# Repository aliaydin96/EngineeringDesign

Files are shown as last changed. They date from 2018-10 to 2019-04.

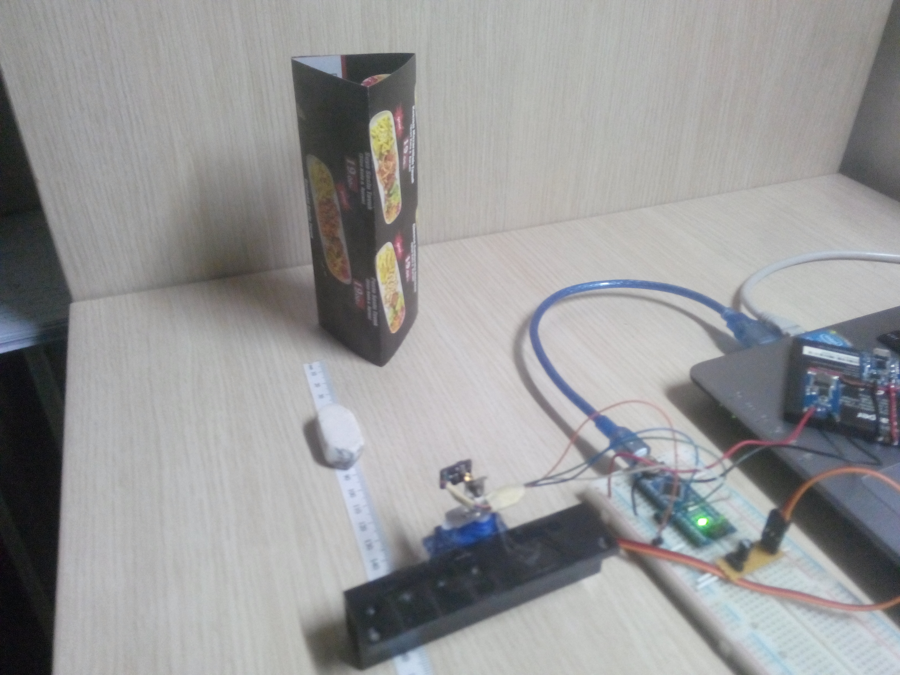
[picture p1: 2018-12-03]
Algorithm/measurements/IMG_20181125_203048.jpg

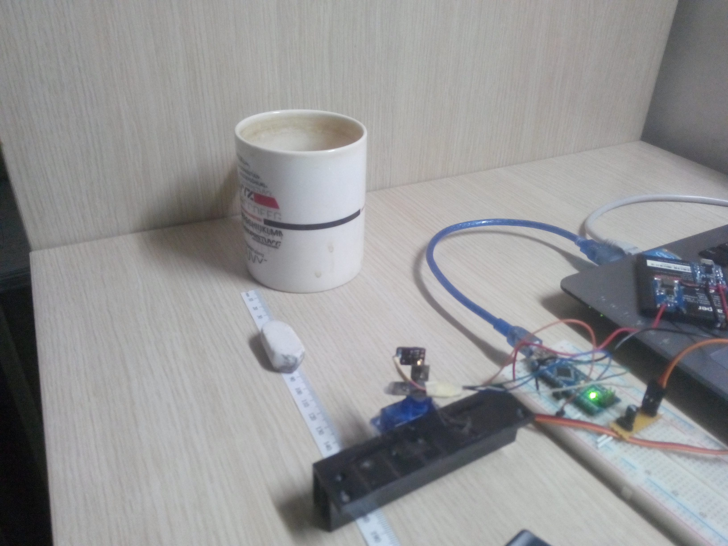
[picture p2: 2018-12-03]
Algorithm/measurements/IMG_20181125_203109.jpg

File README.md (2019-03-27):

# Coni nolur yeni branch açma :*
## Deadlines
* Weekly Reports every monday nights 00:00
* IMPLEMENTATION DEADLINE April 22-26
* FINAL REPORT IS DUE May 10th, Friday (17:00)
* FINAL DEMO (May 13‐ 17 May)
* EE494 - PROJECT FAIR June 14th

## Not To Do (Important!) 
* Öncelikle dosyasınızı başka bir konumda düzenleyin. Pull yapın sonra düzenlediğiniz dosyayı EngineeringDesign klasörüne atıp push yapın.
* Not push before pull! (alan el veren elden üstündür.)
* Never ever try to open another branch
* No fetch, merge, weird forks and anything fancy
* If your push give error do **NOT** force-push. There is no **force-pull** option at the another side.

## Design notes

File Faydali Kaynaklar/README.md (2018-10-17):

# Useful links
## OpenSimpleLidar
[Github Repo](https://github.com/iliasam/OpenSimpleLidar)
## xLIDAR
[Github Repo](https://github.com/JRodrigoTech/xLIDAR)
## LiDAR-Lite v3 ($129.99)
[SparkFun Link](https://www.sparkfun.com/products/14032)
## TFMini Micro LiDAR Module ($39.95)
[SparkFun Link](https://www.sparkfun.com/products/14588)

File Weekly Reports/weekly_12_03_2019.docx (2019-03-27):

RALAZABA Electronics

Weekly Report

Team Members: Ali AYDIN, Anıl AYDIN, Enes AYAZ, Selman DİNÇ, Nail TOSUN

Advisor: Lale ALATAN

Done

We acquired measurements from multiple sensors simultaneously such that the environment sensing unit can achieve 360-degree vision of the environment. The results are explained in Sensor Employment section.

We established the mechanical design and are currently working on 3D Printed parts of Environment Sensing Unit and Self Localization Unit

To Do

We will finish mechanical design and obtain a stable system such that all the components of the robot are placed in the chassis and fixed.

Sensor Employment

In this study, we tested the ability of visualization of the environment using four-fused sensors. The tests took place in the figure 1. As shown in the figure, a cylinder with 5 cm diameter placed at (0 cm,0 cm), a cylinder with 10 cm diameter placed at (54 cm,0 cm) and a triangular prism with 7 cm edge-length placed at (40 cm, -47 cm).

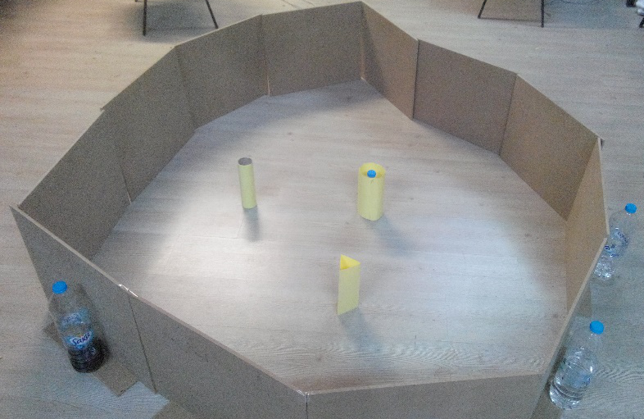
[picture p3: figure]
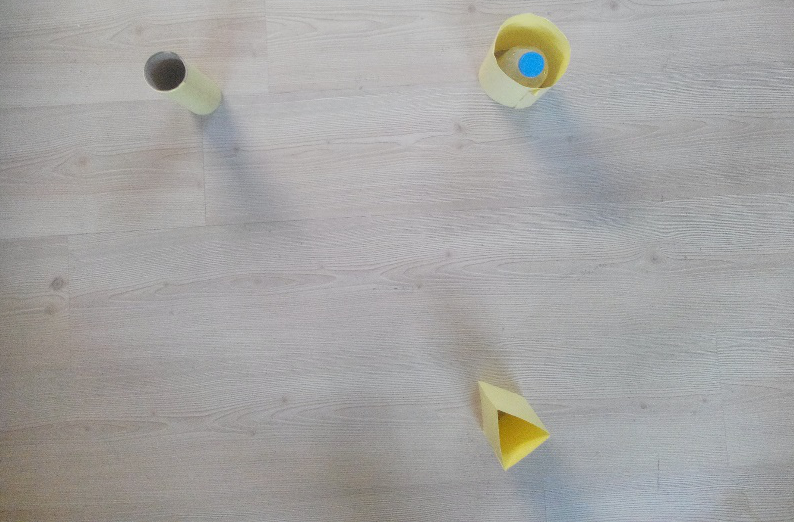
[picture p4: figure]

Figure 1 The test setup

The first measurement was taken from (24 cm,0 cm) point and it is shown in figure 2.

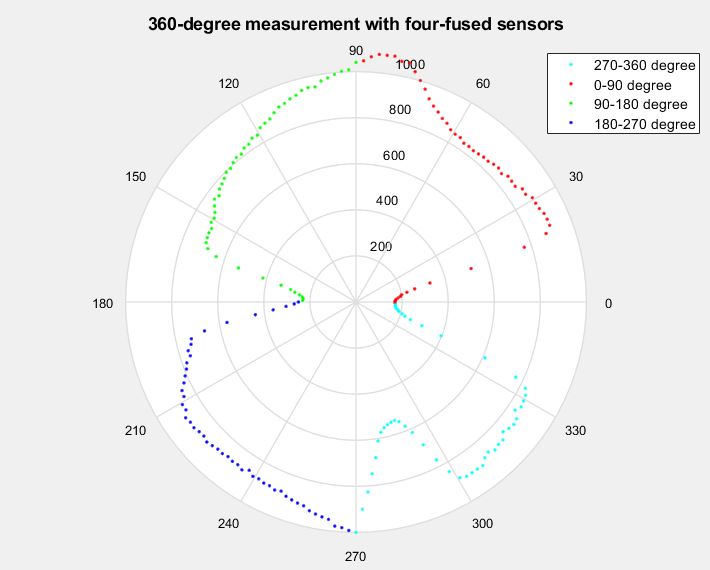
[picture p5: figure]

Figure 2 The first measurement under fluorescent illumination (similar to the case in Cultural Convention Center.)

From the figure 2, the peak for the cylinder with 10 cm diameter is measured at (186mm, 0 mm) and the peak for cylinder with 5 cm diameter is measured at (220mm, 0 mm), which results in app. %3 error.

To test the effect of the sunlight exposure, we took the same measurement under direct sunlight illumination. The result is shown in figure 3.

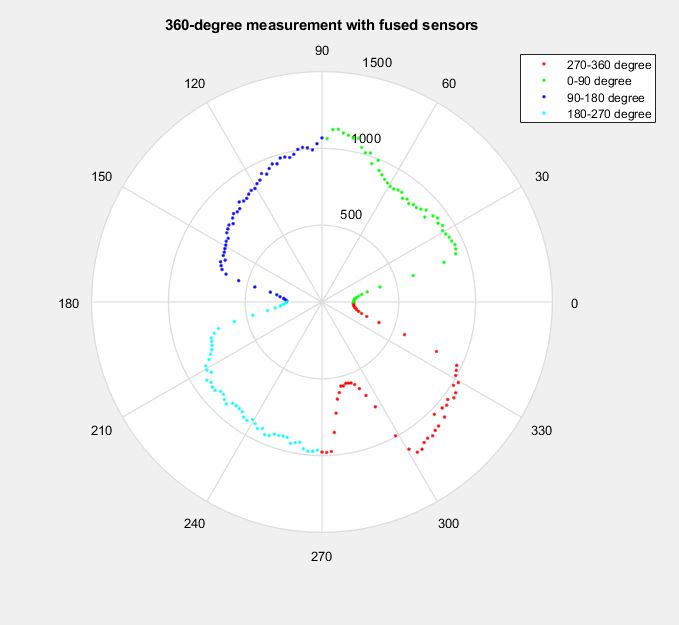
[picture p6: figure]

Figure 3 The first measurement under direct sunlight illumination

At this point, the peak of the left cylinder is at (215mm, 0mm) and the peak of the right cylinder is at (198mm, 0mm). This is expected due to sensor characteristics.

Then, the second measurement was taken at (24 cm, -30 cm) and used to build the resultant map as shown in figure 4. In this figure, the higher portion of the noise does not affect the result significantly. However, for the triangular prism the measurements are shifted. This may occur because of accidental move of the triangular object.

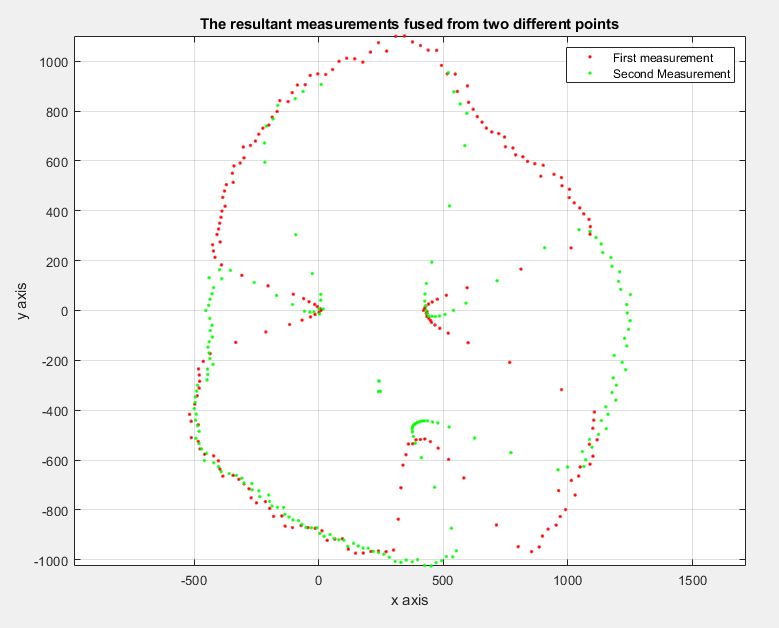
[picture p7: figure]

Figure 4 The resultant map

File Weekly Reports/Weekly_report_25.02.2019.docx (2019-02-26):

RALAZABA Electronics

Weekly Report

Team Members: Ali AYDIN, Anıl AYDIN, Enes AYAZ, Nail TOSUN, Selman DİNÇ

Advisor: Lale ALATAN

Done

Two mouses self-localization method is tested.

We wrote test procedures for both mouse option and encoder readings

To Do

Encoder readings will be tested and compared with the the mouse option.

Kalman Filter will be constructed.

Mechanical design will be built.

Kalman Filter Road-Map

At the conceptual design report, we proposed 5 different ways to sense the robot’s localization. We chose two methods together in order to prevent cumulative errors at the location and heading angle. Therefore, we decided to use a Kalman filter. In order to use a Kalman filter, we should have two measuring methods one is more accurate less frequent other one vice versa.

Our methods to sense location of the robot are two mouses method and encoder reading. To measure how much cumulative error can cause problems at the robot’s operation we wrote a test procedure for two mouse method. Our first thought is the mouse method has better accuracy but sensor data less frequent. The encoder readings are real-time but noisier. However, calculation errors of both two methods are crucial for filter design.

This week, we measure the error of two mouses method. Following week, we will test the encoders.

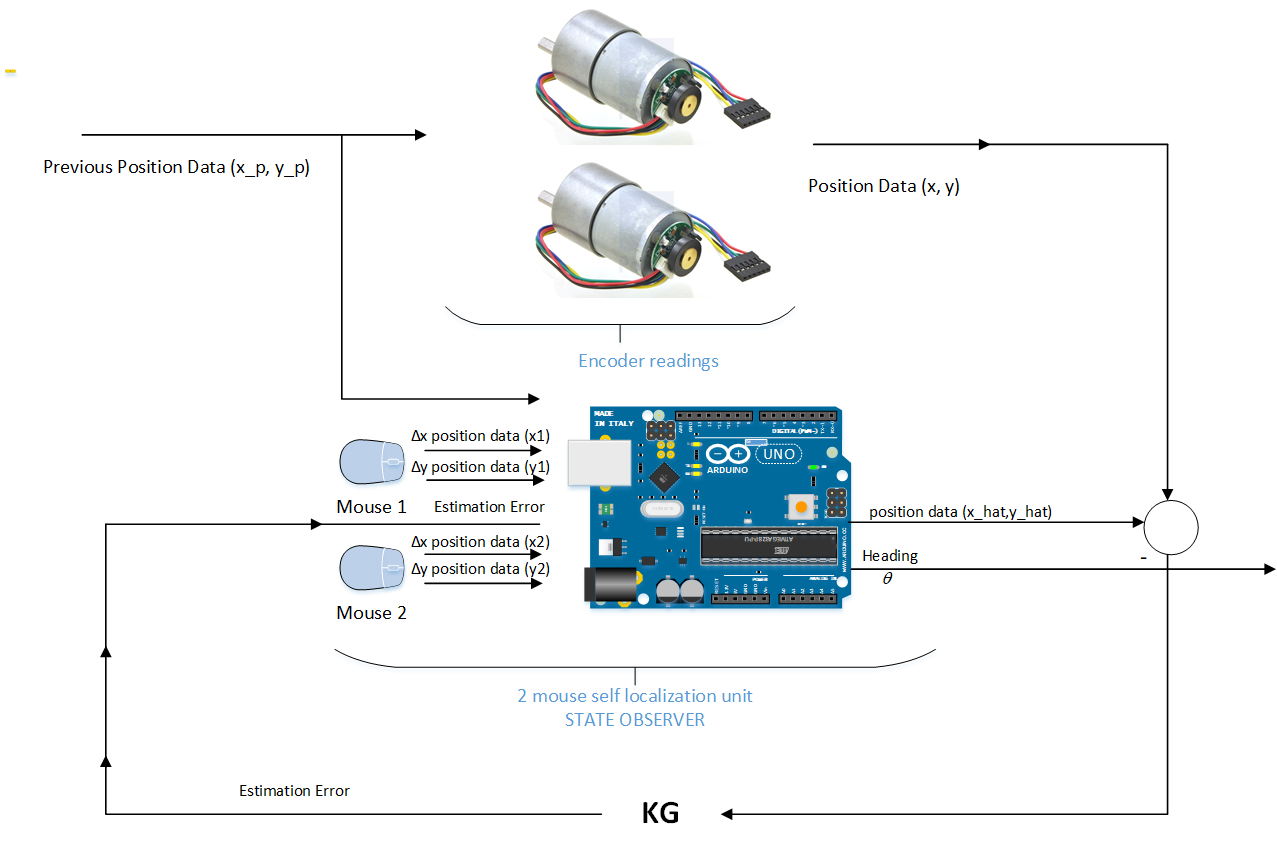
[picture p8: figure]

Figure 1 Kalman Filter Block Diagram

Self-localization (State Observer) Test Procedure

Test Plan

We want to use the 2 mouse method to solve the self-localization problem. In this method 2 separate mouse’s combined to measure both relative distance and heading angle of the robot. To measure errors of this method we planned a test plan.

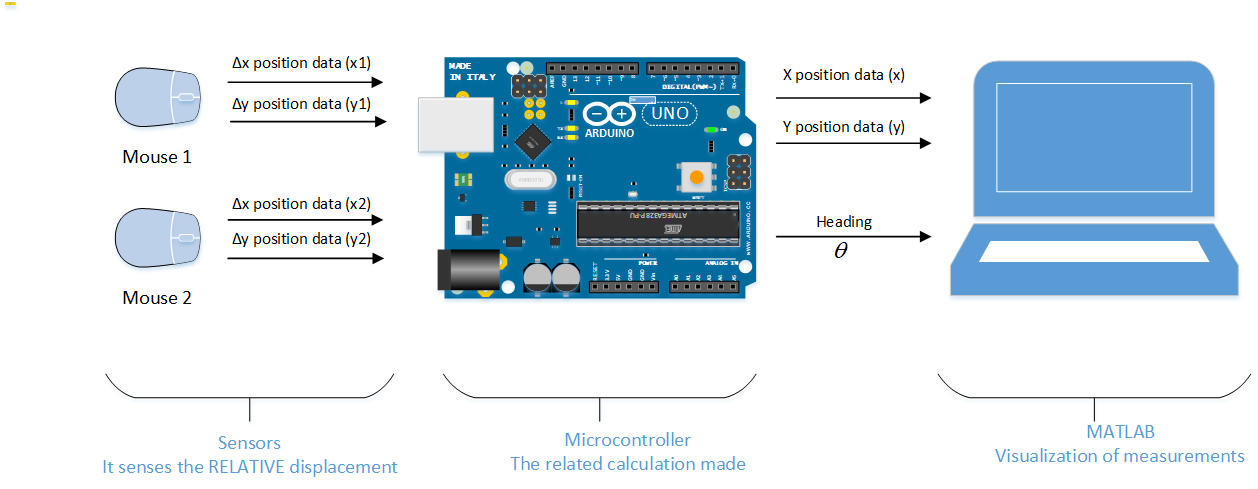
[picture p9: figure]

Figure 2 Block Diagram of the Test Plan

Test Setup

We read the sensor data with Arduino Nano. The related calculations made at MATLAB and Arduino environments. We measure the ground truth using millimetric papers.

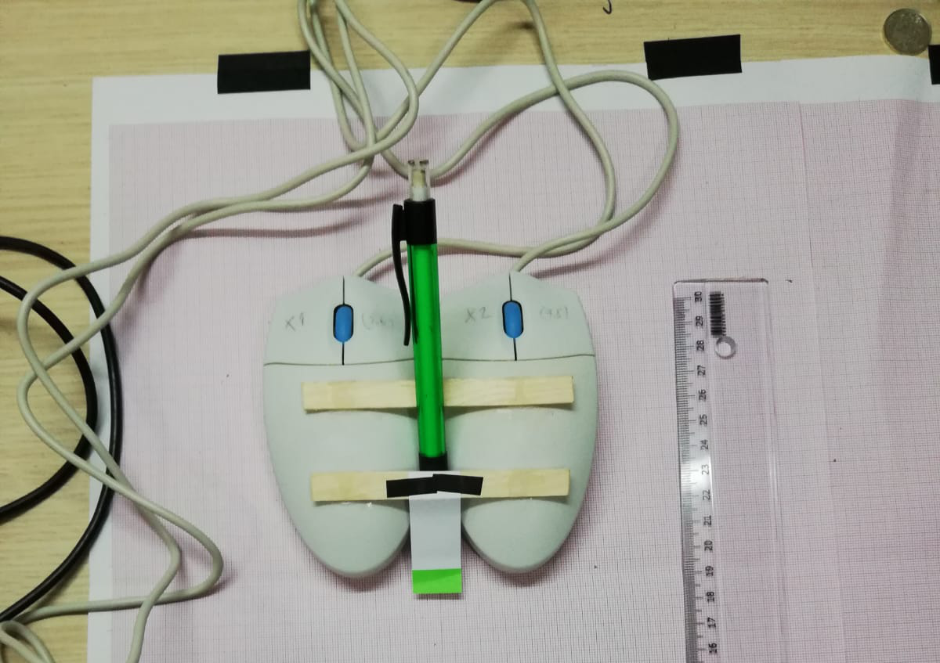
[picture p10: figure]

Figure 3 Test Setup

Test | Expectation
Straight Line 1 at a small distance | Is the unit measure the distance with MEA less than %1?
Straight Line 2 at large distance | Is unit measure the distance with MEA less than %1 Is the effect of cumulating the error seen?
2 Direction movement at an acute angle ( θ<90 ° ) | Is the unit measure the heading angle with MEA less than 1 ° ?
Arc (Quarter circle) | Is the unit measure the final destination with MEA less than %1? Is the unit measure the heading angle with MEA less than 1 ° ?

Table 1: Test Procedure

Test Results

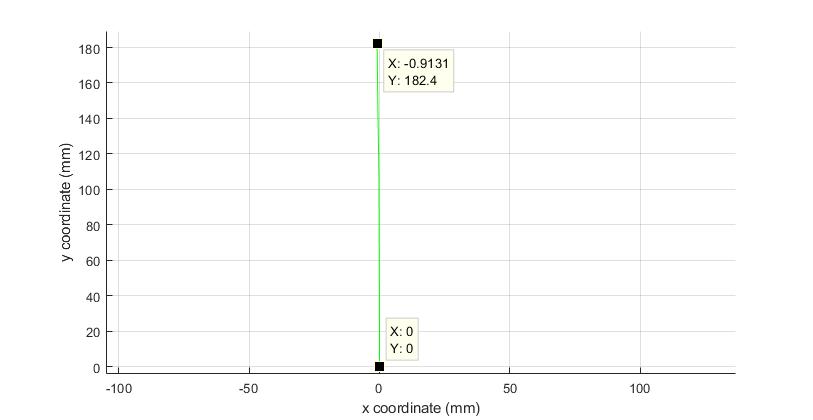
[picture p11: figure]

Figure 4: Test 1 short distance measurement

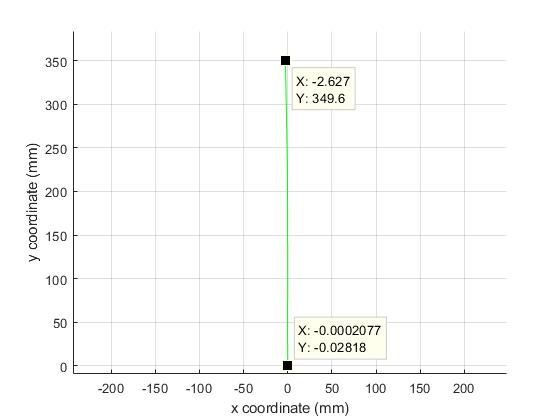
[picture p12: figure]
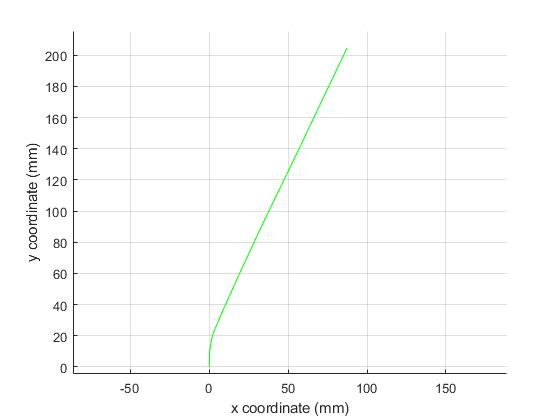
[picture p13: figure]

Figure 5: Test 2 Long distance measurement | Figure 6: Test 3 heading angle

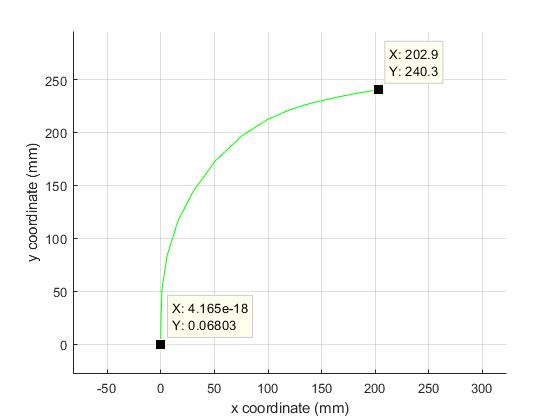
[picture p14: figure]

Figure 7 Test 4 Arc

Errors

Test No | Ground Truth | Measurement | Error PMAE
1 | x = 182 mm | x = 182.4 mm | 0.2 %
2 | x = 350 mm | x = 349.6 mm | 0.11 %
3 | θ=65.5 ° | θ=65.12 ° | 0.58 %
4 | x = 210 mm y = 210 mm | x = 202.9 mm y = 240.3 mm | 7.9%

Table 2 Errors

Conclusion of the test

From these test result we conclude that;

- Two mouse method high accuracy when the motion of basic. (Straight line, L shapes etc.)
- When the roadmap getting complex, the error due to measure is grow cumulatively. Therefore, roadmap algorithm should be robust or cumulative errors should be deleted via filters, i.e. Kalman filter.
- Very possible reason for failure at test for is our system is not sensitive lateral movements like in figure x
- In the case of differential drive there will be no direct horizontal movements or serious horizontal disturbances. Therefore, test 4 error is not critical for our sensing subunit. However, related software update will be constructed next week.

Figure 8: Illustration of horizontal disturbances

Next Week Test Procedures

Test | Expectation
Straight Line 1 at a small distance | Is the unit measure the distance with MAE<% 1?
Straight Line 1 at a long distance | Is the unit measure the distance with MAE<% 1? Is the effect of cumulating the error seen?
2 Direction movement at an acute angle | Is the unit measure the heading angle with MAE<% 1?
2 Direction movement at a wide angle | Is the unit measure the heading angle with MAE<% 1? Is the effect of cumulating the error seen?
Arc (Quarter circle) | Is the unit measure the final destination with MAE<% 1? Is the effect of cumulating the error seen?
Random Path | Is the unit measure the 5 random destination point with average MAE<% 1? Is the unit measure the heading angle with MAE<% 1? Is the effect of cumulating the error seen?
Overall System (Conclusion) | Is the method satisfy our performance requirements?

Figure 9: Test procedures for both mouse and encoder methods

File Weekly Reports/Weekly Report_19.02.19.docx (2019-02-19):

RALAZABA Electronics

Weekly Report

Team Members: Ali AYDIN, Anıl AYDIN, Enes AYAZ, Nail TOSUN, Selman DİNÇ

Advisor: Lale ALATAN

Done

- We tested the accuracy of the distance sensors that we purchased and check the consistency of the sensor under various illumination.
- We tried to drive multiple sensors more than two. We achieved to drive two sensors instantaneously.
- We tested the two-mouse structure to find the heading and location. We failed in algorithm. We conclude our work with the result that we need to re-design our algorithm.

To Do

- We will re-design our self-localization algorithm and will test it.
- We will purchase mechanical chase casing and built it.
- We will focus our research on Critical Design Review Report.

Sensor tests

The experiment is made to test the effect of illumination. In the test environment, the illumination is made by 50-lux fluorescent lamp placed right above the sensor and the object. As a result, the measurements are consistent with the given datasheet and the sensors work flawlessly.

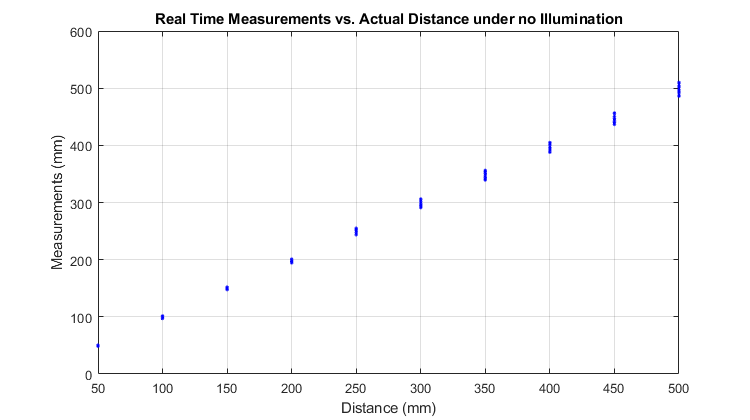
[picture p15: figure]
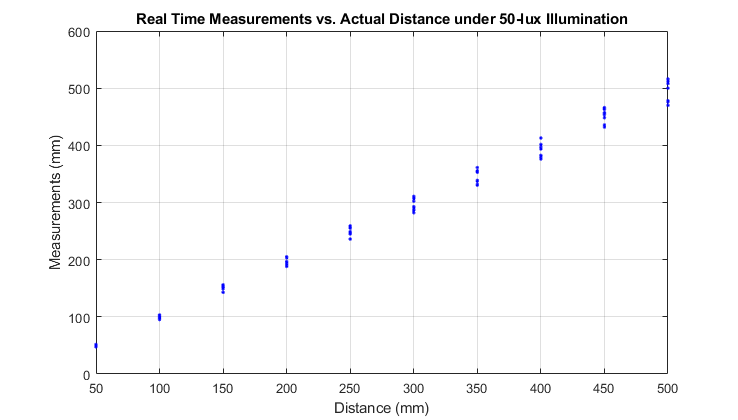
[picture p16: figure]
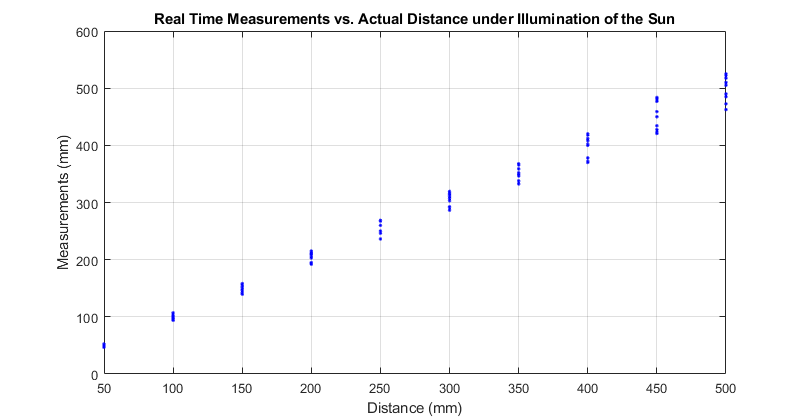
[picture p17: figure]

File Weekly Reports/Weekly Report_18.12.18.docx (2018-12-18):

RALAZABA ELECTRONICS

Weekly Report

Team Members: Ali AYDIN, Anıl AYDIN, Enes AYAZ, Nail TOSUN, Selman DİNÇ

Advisor: Lale ALATAN

Done

- We tried to control the mouse on MATLAB and we drew the path of mouse without using any rotation angle. We just drew on XY plane. The result can be seen in Figure 15.
- We tried to obtain rotation angle by using gyroscope, we realized it only gives information about the direction gravity vector and its rotational output is not reliable. Due to that, we decided to use compass or two mousses to sense rotation of robot.
- We created a simulation environment for shape and center detection. The maps and shapes are in the section of “Shape and center detection simulation”
- After that, we tried to use measured data for shape detection, but our measured data needs to be cleaned in some aspect. For that, we made a modification in our algorithm. The explanation of the modification and the results with measured data is in the section of “shape finder algorithm for measured data”.

To Do

- We will start to write conceptual design report on Wednesday.
- We will try to obtain rotation angle by using two mouse or a mouse and compass.

Shape and center detection simulation

To test our first algorithm for shape and their center detection, we created simple maps with no error using paint. The maps that we tested are shown in from Figure 1 to Figure 4.

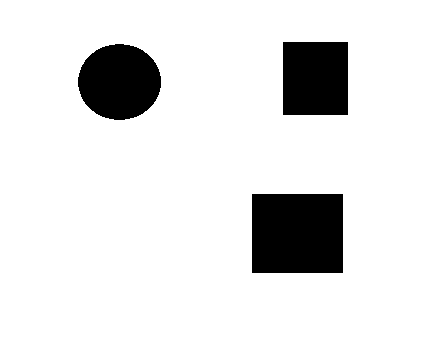
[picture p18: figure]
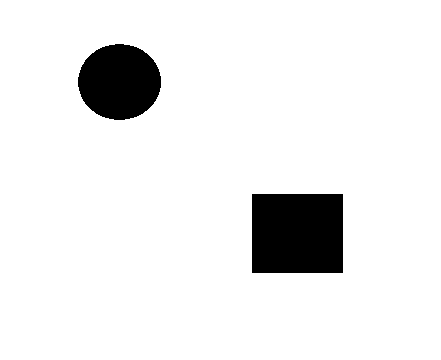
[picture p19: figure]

Figure 1: First Test Map Figure 2: Second Test Map

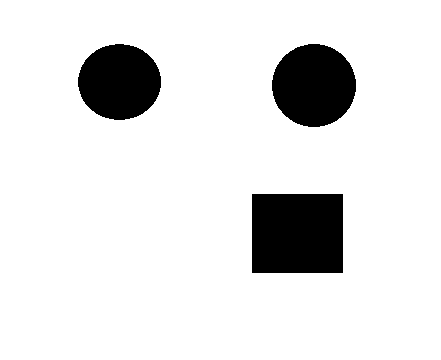
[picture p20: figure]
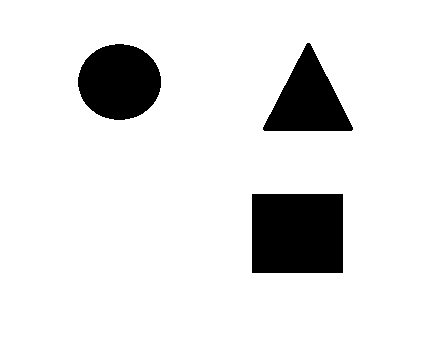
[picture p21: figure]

Figure 3: 3rd Test Map Figure 4:4th Test Map

We created a simulation environment such that, we loaded these maps to a MATLAB script and we selected 3 points for sensing these shapes. From these 3 points, we created lines with different slopes and the intersection points represented the lidar scans. These lines will represent how the map will be seen by the lidar sensor. Our simulation environment is seen like in Figure 5. In the figure, the lines (lidar measurements) is intercepted with the boundaries of the objects. The interceptions are shown in the figure as red dots. The intersection points for 4 different map configurations are shown in from Figure 6 to Figure 9.

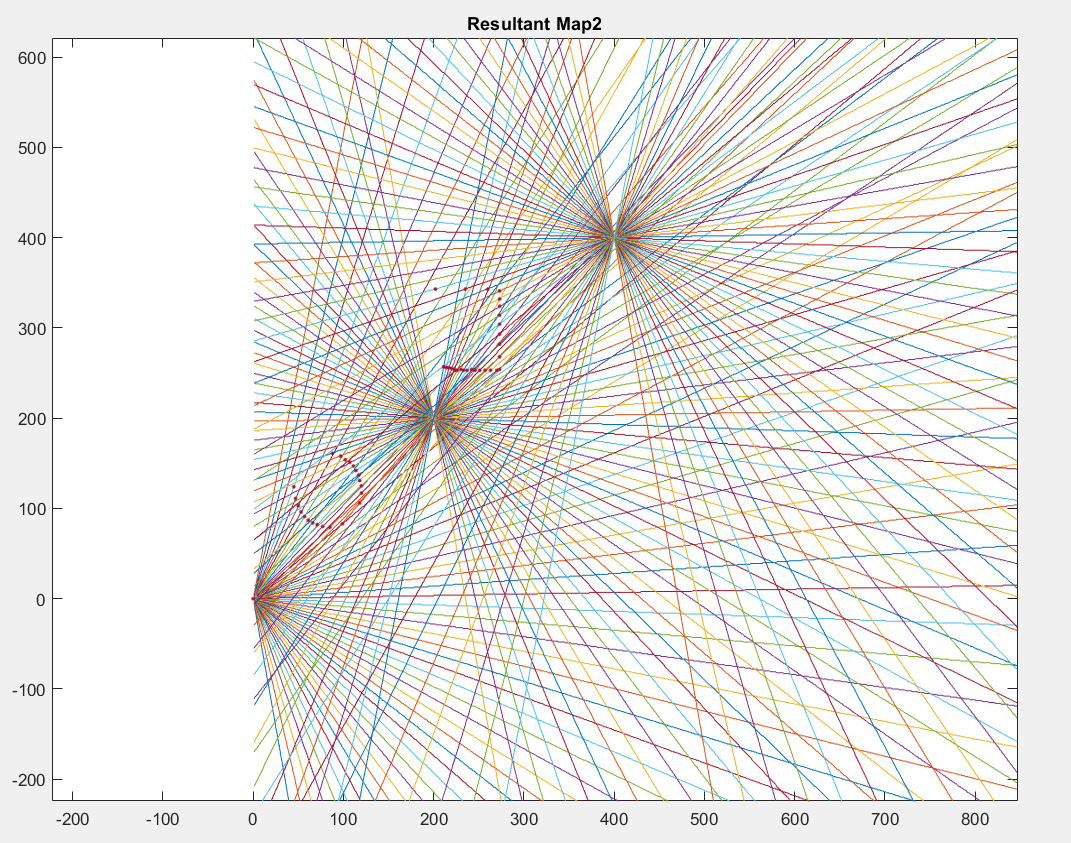
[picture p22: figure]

Figure 5: The simulation environment

After intersecting lines and our objects, some parts of objects are not shown which will be the case in real data. The missing parts of the objects can be seen in resultant maps. We must come up with this problem first. To do that, we combined x and y coordinates of resultant map data and converted these data to an image to be able to process and create objects.

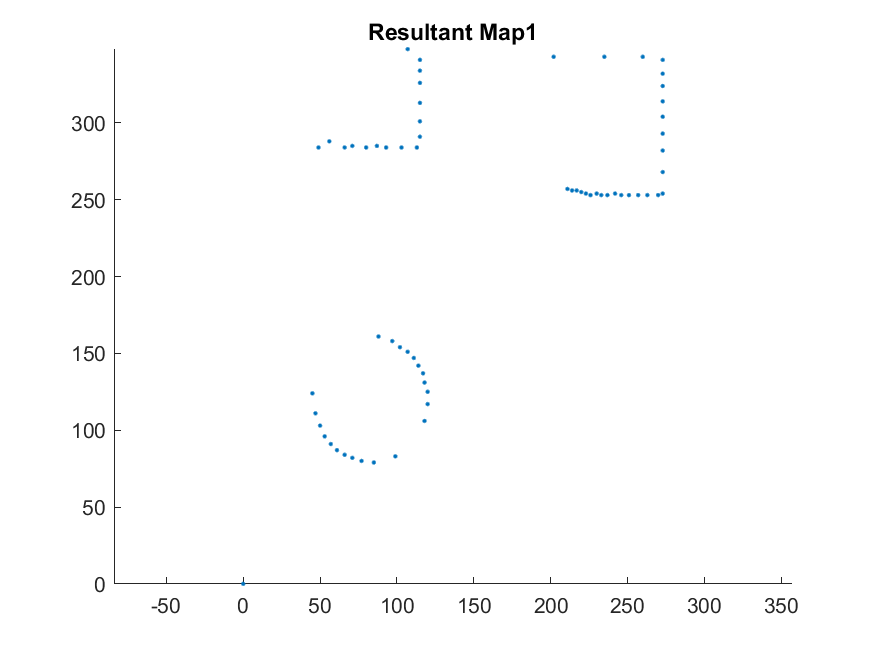
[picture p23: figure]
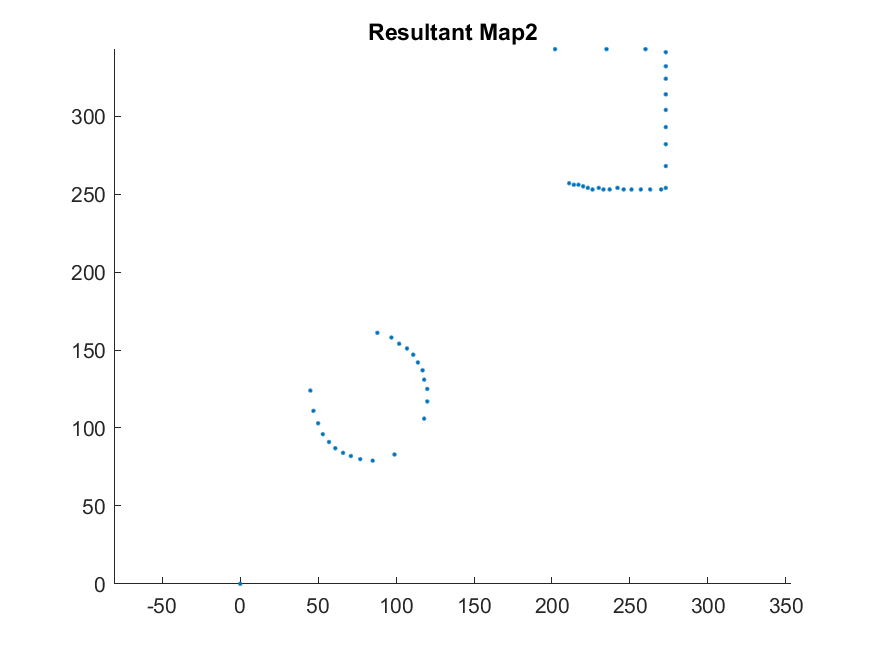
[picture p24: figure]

Figure 6: Lidar Scan Result for 1st Map Figure 7: Lidar scan result for 2nd Map

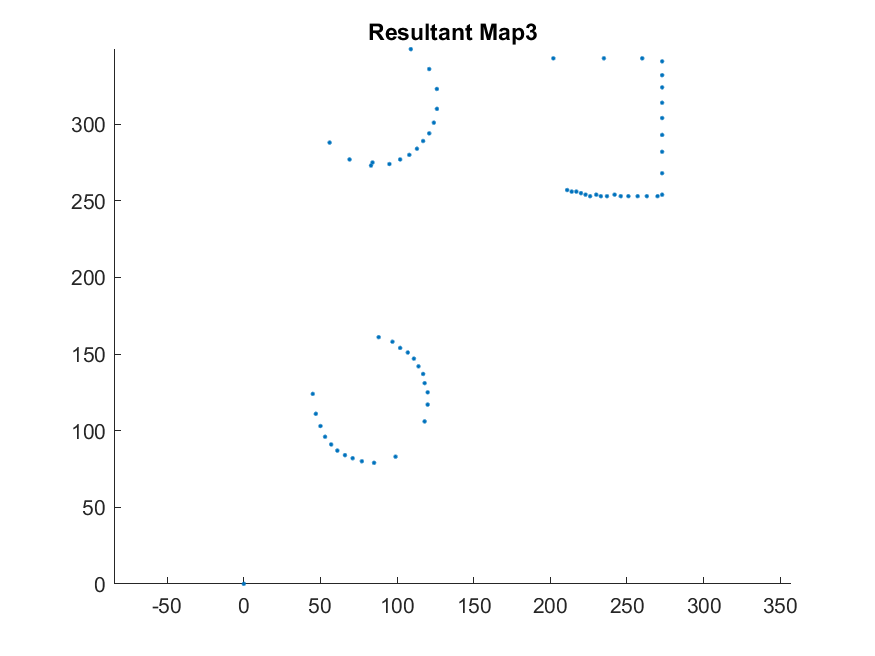
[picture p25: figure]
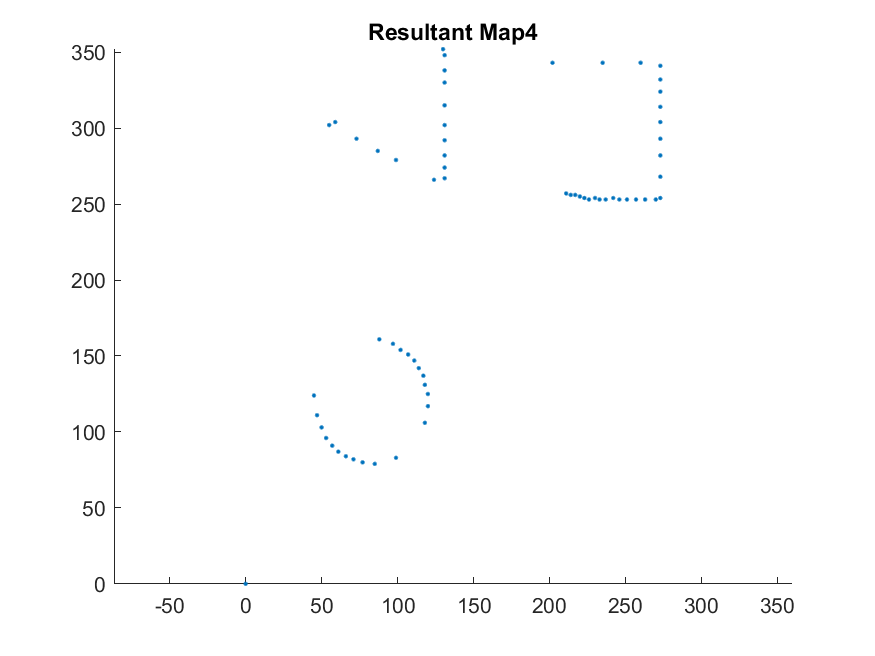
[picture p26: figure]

Figure 8: Lidar Scan result for 3rd Map Figure 9: Lidar Scan Result for 4th Map

Thus, after simulation, we converted resultant maps to images and made threshold operations. The thresholding operation is used to determine the boundaries and edges of the objects for Multiple Kernels. Further readings can be found under the topic “Multiple Kernels for Object Detection”. After thresholding, we found contours in the image and using some constraints such as the area of contours and the length of contour arrays, we created 3 different cases for rectangular, circular and triangular objects. The resultant maps from the missing data are shown in from Figure 10 to 13.


Figure 10:Resultant shapes and centers for 1st Map Figure 11: Resultant shapes and centers for 2nd Map


Figure 12:Resultant shapes and centers for 3rd Map Figure 13:Resultant shapes and centers for 4th Map

Yet, we have some problems about our algorithm which is detection of the triangular object is not working well. We will solve this problem by defining the triangle dimensions to the software as we know them.

Measurement

We set the measurement environment to test our mapping algorithm with real data. The setup, Figure 14-16, has 3 different viewpoints with respect to object. The test objects are scanned via the lidar sensor from three different points. These measurements are merged by using an algorithm that takes a position of sensor (in 2 Dimension) and angle between stationary coordinate system and sensor data. Normally, the lidar will measure the distance with related angle. This angle information is in the frame of the lidar. We need to project the measurements to the global frame of the map. To accomplish this task, the measurements are rotated using rotational transformation matrix and positioned according to the position vector of the lidar. The output of algorithm is illustrated in Figure 14 to 16.

Later, the obtained data will be fed to the object finder algorithm.


Figure 14 First Test Map and its output


Figure 15 Second Test Map and its output


Figure 16 Third Test Map and its output

Outputs of shape finder algorithm for real measured data

When we tested our shape finder algorithm with real erroneous data, we had some problem. Most important problem is that the spaces between measured points are large and this causes that our algorithm can find wrong contours. To eliminate this, we added new points to resultant array by adding neighbor points of real data clouds. After that, our thresholding operation worked and we were able to find true contours. The output for rectangular object is shown in Figure 17. We found the center of rectangle as 146,135. The real center was 146,140. This means that we had 3% error for y coordinate of center.


Figure 17: Output of rectangular object

The output for cylindrical object is shown in Figure 18. For cylindrical object we found the center as 154,135. Real center was 146,140. Thus, we had 6% error for x coordinate and 3% for y coordinate.


Figure 18: Output of cylindrical object

The output for triangular object is shown in Figure 19. Here, we found the center as 148,146. Real center was 184,130. We had 24% error for x coordinate and 12% error for y coordinate.


Figure 19: Output of triangular object

These results show us that, while measuring data, we need to have some improvements for better mapping since we need very clear input for shape finding in our case. Another result is that to detect and find the shape of triangular object is hard and, we must modify our shape finding algorithm for more accurate results.

For Mouse Application

We connected a trackball mouse to Arduino and to obtain a graph, and we took data on serial port by using MATLAB. Therefore, as seen Figure 20, we track mouse on the graph. To obtain tracking line, we drew vector between two point that sensed from mouse in a certain time. The resolution of tracking is dependent to the DPI (Dot Per Inch) ratio. In our case, we used 255 Dpi mouse, then we has 100 micrometer resolution of tracking.


Figure 20: The path realization for arbitrarily-moving Trackball Mouse.

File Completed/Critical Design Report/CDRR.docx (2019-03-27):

Ralazaba Electronics

PROJECT AMR

Critical Design Review Report

# A device trying to extract the plan of their surroundings

Prepared for

Assoc. Prof. Lale ALATAN

Project Start Date: 30.10.2018
Project Completion Date: 18.05.2019

Project Duration: 7 Months

Introduction

In this project, the main objective is to design an autonomous robot which plans a bounded environment containing an unknown number of objects by telling the number of objects, their shapes, sizes, and centers, produce a map and send it to the monitor. Moreover, the robot should finish this planning operation in the shortest time, and minimum error as possible. Main features of the robot are:

- To move in x y directions a bounded environment by visiting all regions of the environment
- To make self-localization for detecting the current position of the robot in real time
- To sense objects and bounds of the environment
- To get all necessary data from the objects and environment and combine these data and transfer to the data processing unit
- To eliminate noisy measurement errors as much as possible to increase the reliability of the map
- To process data and determine the number of objects, their shapes and their center information

These main features are also the basis of subsystems of our project. In Conceptual Design Report we categorized our solution approaches for each submodule. Currently, we made some experiments for our subsystems and determined the best solution for each subsystem and finalized our design.

The cover of the CDRR shows our frozen final solution can meet specified performance requirements with a predefined budget, schedule, and each of its subsystems within other system constraints, such as time, power, and accuracy limits.

The first part of this report, we explain the overall system description. Then, we explained our subsystems in detail with giving block diagrams, signal interferences, input-output relations as well as compatibility analysis. After that stage, we examined the performances of subsystems and questioned compliance with our requirements. Test procedures, the measure of success, test results and our conclusions are also explained in detailed.

The final part of the report consists of the resource management; a detailed breakdown of planned work, team’s work sharing as well as Gantt chart, cost analysis, power analysis, and distribution diagram.

Overall System Description

In this project, the robot extracts the plan of the closed region autonomously. Also, it defines the objects in the aspect of shape, size and center coordinates. There are some requirements and the requirements are provided by the subsystem level. There are 6 subsystems which are Self-Localization Unit, Decision and Control Unit, Motion Unit, Sensing Unit, Power Unit, and Data Transfer. The overall block diagram of the system can be found in Figure 1.


Figure 1 A detailed block diagram with signal definitions and voltage levels

The devices start with the start command. Then, it senses the environment and takes the data points (Objects and walls). A mapping matrix is created. If the area of the map is not filled enough, the device creates a destination point and moves. Otherwise, the map is sent the object recognition algorithm. The map and results of the object recognition algorithm are transferred to the monitor for displaying the map to the user. The overall flow chart of the system can be found in Figure 2.


Figure 2 Overall flow chart of the system

Self-Localization Unit

The robot is not stationary. The position and heading angle changes with respect to its movement. Because of all, it is required to obtain a position and heading angle to create relate the robot’s measurements to an overall map. We solve this problem with High-Resolution Movement Tracking Sensor (or it is basically a part of a mouse). The HRMT sense changes in x and y at each 100msec. The data are processed by the microcontroller and the position and heading changes are created. Self-Position is at origin and heading is 90 degree at first starting. Then the changes in heading angle and position are added.


Figure 3 System level interactions of Self Localization Unit with signal interpretation

Materials:

- HRMTU: High-Resolution Movement Tracking Sensor sends a change in 2-dimension space at each 100 msec., 2 Trackball Mouse.
- Encoder: The motion of the motor is measured by the encoder to find the change in 2-dimension space.
- Microcontroller: It governs timing and reading of the HRMTU data and Encoder data, Arduino Nano

Inputs and Outputs:

Power Input: 5 V for HRMTU, Encoders and microcontroller.

Data Output: Serial data of Self Position and heading angles of the devices for each 100 msec.

Decision and Control Unit

Decision and Control unit governs the other unit and processes the data. Mapping algorithm adjusts the measurement of sensing unit by the self-localization and creates the real data. Also, path finder controls the map and find the unseen points of the map. After the path finder makes shape recognition starts, the devices stop and the taking data finishes. The Shape Recognition algorithm creates the shape, size, and center of the object and creates a map as images and sends those to the data transfer unit. Block diagram of the unit is illustrated in Figure 3.


Figure 4 System level interactions of Decision and Control unit with its signal interpretation

Materials:

Microprocessor: For operating the algorithms, Raspberry Pi 3 B

Inputs and Outputs

Power Inputs: 5V with 1A capability

Timing Outputs: Adjusting the flow of operations

Measurement Inputs:

- Taking Objects and walls data from 4 distance sensors
- Taking self-localization information from High-Resolution Tracking Module (HRTM) and DC motors encoders

Destination Outputs: Sending PWM’s of motors for movement

Mapping Outputs: Sending final map data with different headers (shape, size, and center) to the data transfer unit

Motion Unit

The motion unit is required for the movement of the devices. The movement of devices are provided by a differential drive with two motors with encoders. The PWM data are created by the decision unit and these motors are driven with PWM by using motor drivers. The block diagram and signal definitions are in Figure 5.


Figure 5 System level interactions of Motion Unit with its signal interpretation

Materials:

DC motors: 2 DC motor to move 2Dimension

Motor Drivers: It controls the speed of the motor by PWM

Inputs and Outputs:

Power Input: 6V - 0.6A

PWM Input: PWM inputs to adjusting motor speed and movement to a destination point.

Sensing Unit

In this unit, we need to determine the objects that surround the device. To determine the positions and types of objects, we need to transfer the field into a binary understanding of the device. To accomplish this task, we need to understand whether there is an object or not. Thus, we use the ‘distance sensor’ to detect the object.

Figure 6 shows the block diagram of the sensing unit. There are 4 distance sensors which placed on 90 degrees differences. The sensors communicate with microcontroller by using I2C Communication protocol. The sensors are used like LIDAR. Each sensor is rotated by a stepper motor. Thus, each measurement four sensors collect data in 360 degrees totally. The stepper motor is controlled by using a stepper driver.

Measurements occur while the device is stationary. It is sent by the decision unit. After the four sensors rotated 90 degree, the outcome data are stored to convert serial data to distance matrices in the shape of polar coordinates. Also, the data are controlled by the sensing unit to avoid false data. The data are stored with consecutive angles. The difference of radius of each consecutive angle is controlled if the difference is much more than average distance, these data will be erased.

Materials:

4 Distance Sensor: Communicate with I2C protocol with microcontroller. The measurement time is taken from Microcontroller.

Step Motor: Driven by a stepper motor, the position of measurements is logged.

Microcontroller: It provides communication with the Decision Unit. Also, it governs the timing and storing of data.

Input and Outputs:

Power Input: 6 V DC for step motor and stepper driver. 5V for sensor and microcontroller.

Measurement Time Input: Time of taking data is adjusted by decision unit while the device is stationary.

Measurement Coordinates: Measurement of the distance for 360 degrees are sent in the set of polar coordinates to decision and control unit after the measurement operation finished.


Figure 6 System level interactions of Sensing Unit with its signal interpretation

Power Unit

Power unit supplies all electrical components with DC voltages at the required level. Our power unit includes Li-Ion Cells with parallel and series to adjust the voltage and current ratings. Our electrical components operate at different type of DC level. There are 3 DC levels. 3.3 V DC is used for the main microprocessor, 5V is used slave microcontrollers and sensors. 6V DC is used for Motor drive. In Figure 7, the power unit block diagram can be found.


Figure 7 System level interactions of Power Unit with its signal interpretation

Materials:

- Li-Ion Battery: Supplying power
- Buck Converters: It controls the voltage level for a different subsystem.

Inputs and Outputs

Outputs: 3 different voltage level for subsystems.

Data Transfer


Figure 8 System level interactions of Data Transfer with its signal interpretation

This is the final step for the project. As shown in Figure 8, The unit takes the map and properties and sends the data wirelessly to show the output.

Materials:

- Wi-fi Module: Providing wireless communication

Inputs and Outputs

Power Input: 3.3 V for Wi-fi Module

Image: Final version of the overall map that contains shape, size, and center of objects

Mechanical Drawings

a) | b)

c) | d)

e)


Figure 9 Mechanical Design of the overall project (a, b: isometric view, c: front view, d: top view, e: side view.)

Requirements

Motion Unit

- Motors should move with an average of 3.5 cm/sec velocity.
- Motion unit should get the destination data from the decision and control unit and should convert this data to PWM signals to move motors
- The encoders should give position data to the localization unit continuously.
- Motor should be able to bear on the weight.

Sensing Unit

- Sensors should be oriented to sense the environment with 360-degree range.
- The distances from 10 cm to 40cm should be sensed by the sensors to transfer the points to the decision unit because the optimum measurement range of the sensors that we used is from 10 cm to 40 cm.
- Sensing unit should generate 80 data per second.
- Sensors should give data continuously to operate in a synchronized way.

Decision and Control Unit

- The unit should combine data coming from the localization unit and sensing unit to obtain destination path and map data.
- Path planning part should give destination distance and heading to the motion unit.
- Mapping part should give x and y positions of data points coming from the sensing unit to generate a map.
- Object recognition part should collect data point position information and generate contours.
- Object recognition part should decide the types, centers of the objects.

Power Unit

- Power unit should have the ability to supply 4 A current at 5 volts at the time such that robot dissipates maximum power.

Localization Unit

- High-Resolution Tracking Module (HRTM) should give position data with less than 3% error.
- Kalman filter should model error and using the model, the filter should compensate the error.
- Localization unit should send the current position of the robot to the decision and control unit.

Data Transfer Unit

- Transferring Data properly from devices with wireless

Design Modifications

- The number of sensors in the sensing unit is increased to 4. With this modification, we are able to sense the environment in 360-degree range. With this ability, we can sense the environment at a larger range with one round turn.
- Instead of a servo motor, we used a step motor to rotate the sensing unit. Servo motor has some nonlinearities and because of the effect of nonlinearities, angle change in servo motor is not accurate. Step motor rotates with 1.8 degree per step and this can be decreased to 1/16 of 1.8 degree. This rotation is mostly linear and some distortions coming from the linearity of the rotating device is eliminated with this change.
- We created a two-dimensional interpolation algorithm in the decision unit. This improvement gives us more data points to process in the object recognition part. As the number of data is increased, distances between points which are sensed in the sensing unit are closer to each other in image and shape finder algorithm can operate more efficiently. An illustration of two cases is shown below.

Compatibility Analysis of Subsystems

Motion Unit

In this unit, both input and output exist since to move in the field, we need to give direction and destination distance to motor. To drive the motors we need a driver and we feed this driver with pwm signal from decision unit because we can arrange the speed of motors with pwm easily.

Also, to help localization, we need encoder data. Encoder gives mm data with respect to the device’s direction to localization unit.

To supply power, we feed this unit with two different voltage level 5V and 12V. 5V is for motor driver and encoder part. 12V is for DC motor part.

Sensing Unit

We can divide two subblock. One of them is collecting data from distance modules. Another module is rotating the sensing unit. Collecting data part gives distance between devices and objects in mm to decision and control unit.

To rotate sensing unit, we use stepper motor and to drive, we should command to it’s driver.

To supply power, we feed this unit 5V.

Decision and Control Unit

We can analyze this unit in three different part. First part is path finder. This unit takes XY coordinate and heading direction of the device from the localization unit. According to these data, it can specify the path. Second part is mapping. This unit takes XY coordinate and heading direction from localization unit and distance data from sensing unit. After interpreting the data, it gives the result to object recognition part. Third part is object recognition part. This unit takes XY coordinate matrix. it interprets the data and specifies the object’s types and centers. Then, it gives the data to transfer unit.

For this part, we use raspberry pi and it need 5V to operate.

Power Unit

Power unit should be able to supply different voltage level to the device. The unit can be split in two part. One of them is Li-Ion Battery a main power supplier at 7 V and 5 A rated. Other one is buck-converters that converts the 7 V DC to 3 different voltage level.

Localization Unit

We can analyze this unit in three different part. First part is high resolution tracking module. This module gives XY coordinate to filter. Second part is encoder module. Encoder also gives position data with respect to heading direction. Third part is filter unit. In this part, we use Kalman filter. Then, filter unit gives XY coordinate and heading direction to decision unit.

Data Transfer Unit

This unit takes an image from decision unit and sends a mail map of the environment and properties of objects.

Compliance with Requirements

Motion Unit

To extract map clearly, the device needs to move. One requirement for selection of motor is that motor is able to bear on the weight. The device has one stepper motor, two microcontroller, one microprocessor and battery. The device will be more than 1.5 kg. Selected motor can bear on 10 kg, but it works inefficient according to datasheet and it operates maximum efficiency for 2 kg. The motor can go speed of 210 rpm. With respect to wheel radius, it can reach 43 cm/s. As requirement, we specify as 3.5 cm/s. If we take good results, we can speed up the device and we can finish mapping shorter time. Moreover, motor has encoder and we use encoder results for localization unit.

Sensing Unit

For scanning whole environment, we can use one distance sensor, but this takes a lot of time and we want to finish shorter time. For this purposes, we decided to use four distance sensors. Then, we rotate the unit 90 degrees for 360 degrees scanning. Also, one module can take almost 30 data per second and with four module, we can take at least 80 data per second and we achieve one of the requirements. Moreover, we need higher resolution to classify the objects and we decrease the step angle of stepper motor.

Decision and Control Unit

The most critical part in the project is decision and control unit since this unit takes position information, interprets it and with respect to that, occur destination part. Also, this unit occurs map that by taking different sensing data and classifies the objects. Shortly, this unit will make a lot of work. For this purposes, we cannot use a microcontroller, we need stronger controller and we decided to use raspberry pi. It can make parallel processing and it has stronger CPU. Also, thank to specific libraries, it can make faster calculation.

Power Unit

To work the device, we need a power source in the device. For this reason, we decided to use li-ion battery since they are cheaper and safer than li-ion battery. With respect to its number, we can arrange supply rating.

Localization Unit

We need correct location of the device to extract the map clearly. For this purposes, we need high resolution module and we decided to two mouse. Mouse can take almost 100 samples per second. We find this result by measuring time to take 100 samples. However, sometimes during the test, trackball can slip, and we take wrong result. To avoid this problem, we need another unit to measure the distance and we bought DC motor with encoder. Encoder gives result higher error, but we use Kalman filter to eliminate the error. Then, we take less than %3 error. Also, we took more error when mouse moves in arc path. We think that if the device follows straight path, we can decrease error rating.

Data Transfer Unit

After finishing scanning, we need to show extracted map and properties of object in the area to user. To achieve this, we use raspberry pi Wi-Fi module. We connect the device to the internet, and we send an email to user after finishing whole process.

Test Procedures and Results

Sensing Unit

Sensor Employment

At the conceptual design report, we proposed measurements for environment sensing is established via 2 distance measurement sensors. However, considering our design criteria which is short operation time, the speed of measurement is not enough. Each sensor takes 18-25 measurements per second as shown in Figure 10. In the Figure 11, the sensor measurements are transmitted via I2C communication protocol and its transmission base frequency is 100 kHz as shown in Figure 11. For this case, the transmission window takes 40 milliseconds. The idle mode that the sensor takes the measurements and waits for the transmission window is at minimum 20 milliseconds. In the figure, it is chosen to be 50 milliseconds for stable operation. This limits the transmitted data size.


Figure 10 Data transmission of vl53l0x using I2C (CH1 and CH2 are clock and data signals respectively).


Figure 11 Data transmission of VLX53L0 using I2C (CH1 and CH2 are clock and data signals respectively.).

To acquire faster operation of ability of visualizing environment, we came up with using multiple sensors. In our critical design, we came up with using four vl53l0x arranged as in Figure 12. With the motion of the sensor in 90-degree radian, we obtain 360-degree visualization of the environment.


Figure 12 Sensor Orientation

To be able to use four sensors, we needed to make changes in the library code of the sensor provided by its manufacturer STMicroelectronics. In first modification, we changed the trigger mechanism of the sensor and its timeout counter such that the measurement duration is shorten. As shown in Figure 13, the data transmission window is shortened to sequentially read the measurements from the sensors. As shown in the figure 13, the data transmission window takes 12.5 milliseconds with idle mode of 20 milliseconds when I2C clock rate is 100 kHz, the same as previous case.


Figure 13 Data transmission of VLX53L0 using I2C (CH1 and CH2 are clock and data signals respectively.).

To acquire multiple measurements from different sensors at the same time, we fuse all the sensor measurements into single transmission window as it can be seen from the figure 14. With this result, we can obtain 80 measurements per seconds.


Figure 14 Data transmission of VLX53L0 using I2C (CH1 and CH2 are clock and data signals respectively.).

The timing diagram of the sensors is shown in Figure 15.


Figure 15 Timing diagram of the sensors

To examine the four distance sensors configuration, we established a setup with 12 walls and 3 objects in the Figure 16. We tried to take data for specified environment in the project description. We used 1 step to rotate the sensors and we rotate the sensors 90 degree clockwise. We took the result from three different points. We took self-localization data with hand measurement. Then, we merged the three different data points in the MATLAB, and we took result in the figure xxx.


Figure 16 The test setup for four sensor configuration.


Figure 17 The resultant map of the setup.

Test Results

With this test setup, an improvement in the algorithm is required. From the resultant map in the Figure 17, the measurements overlap. However, for each sensor measurement, the data consists of accumulated and fringing measurements. The fringing measurements prevents our mapping algorithm to detect and classify objects. This problem is to be solved via average discard filtering.

Localization Unit

Test Setup

We read the sensor data with Arduino Nano. The related calculations made at MATLAB and Arduino environments. We measure the ground truth using millimetric papers. The mouse test setup can be seen in Figure 18.


Figure 18 Mouse test setup

Test Setup

Test | Expectation
Straight Line 1 at a small distance | Is the unit measure the distance with MEA less than %1?
Straight Line 2 at large distance | Is unit measure the distance with MEA less than %1 Is the effect of cumulating the error seen?
2 Direction movement at an acute angle () | Is the unit measure the heading angle with MEA less than 1 ?
Arc (Quarter circle) | Is the unit measure the final destination with MEA less than %1? Is the unit measure the heading angle with MEA less than 1 ?

Table 1: Test Procedure

Test Results


Figure 19 Test 2 results | Figure 20 Test 3 results


Figure 21 Test 4 results


Figure 22 Test 1 results

Errors

Table 2 Errors

Test No | Ground Truth | Measurement | Error PMAE
1 | x = 182 mm | x = 182.4 mm | 0.2 %
2 | x = 350 mm | x = 349.6 mm | 0.11 %
3 | θ = 65.5° | θ = 65.12° | 0.58 %
4 | x = 210 mm y = 210 mm | x = 202.9 mm y = 240.3 mm | 7.9%

Conclusion of the test

From these test result we conclude that;

o Two mouse method high accuracy when the motion of basic. (Straight line, L shapes etc.)

o When the roadmap getting complex, the error due to measure is grow cumulatively. Therefore, roadmap algorithm should be robust or cumulative errors should be deleted via filters, i.e. Kalman filter.

Resource Management

Cost Analysis

The detailed cost analysis table of the robot is at Table 3.

Table 3 Cost Analysis

Product | Price/Product ($) | Number of Pieces | Total Cost ($)
Raspberry Pi 3 B | 41 | 1 | 41
Arduino Nano | 2.32 | 2 | 4.64
Trackball Mouse | 1.9 | 2 | 3.8
VL53L0X Sensor | 2.5 | 4 | 10
L298N | 0.44 | 1 | 0.44
Step Motor | 5.99 | 1 | 5.99
Step Motor Driver | 1.1 | 1 | 1.1
Motor Set | 23 | 1 | 23
Battery cells | 3.7 | 6 | 22.2
Plexi Chassis material set | 7 | 1 | 7
Bolt & Screw Set | 5 | 1 | 5
Total | | 21 | 130.4

Power Analysis

In this project, the power consumption varies as the robot follows its flow chart.

Depending on which subsystem is active and receiving command the power consumption is given in Table 4.


Table 4 the measured power consumption of the subsystems for their designed operation.

Power Distribution Diagram

The power distribution is shown in Figure 5. Using the power distribution diagram can be specified with the information given in the measured power consumption table.

Table 5 Power Distribution Table

| | Rated Volatge(V) | Rated Current(A) | Power(W)
Line 1 | Desicion and Control Unit | 5 | 1 | 5
Line 2 | Motion Unit | 12 | 1,20E+00 | 14
Line 3 | Sensing Unit | 5 | 0,11 | 0,55
Line 4 | Self Localization Unit | 5 | 0,5 | 0,25
Line 5 | Sensing Unit(Stepper) | 12 | 1 | 12


Figure 23 The power distribution of the overall system

Project Schedule

Our Gannt chart is at the Appendix with A3 size.

Conclusion

Our solution idea starts with data collection from the environment. From the first collection, the robot finds the nearest object according to its location and constructs a path. After completion of the path, the robot takes measurements at different points from the object and labels it as 'seen'. Then it starts searching for the newest 'unseen' object. Once the robot has tagged all objects and identified their types and locations, the robot transmits the map to the monitor over a communication channel.

In the first part of this report, we investigated detailed system analysis and subsystem level solutions. Our subsystem requirements were determined, and subsystem level solutions was created. There were some solution approaches at conceptual design report, we chose one of them solution with respect to our requirements. Also, we had some modification at some solutions. In addition, the subsystem level communication with each other are created and control and power signals are determined. Besides, the mechanical design and power distribution were created. The last part of the report consists of a detailed planned work, the work sharing of the team as well as the Gantt chart to present the project timeline. Test procedures, measurement of success, cost analysis and feasibility are also explained.

Disclaimer

Design specified in the report complies with the standards of the selected project.

Ali Aydın Anıl Aydın Enes Ayaz

Nail Tosun Selman Dinç

Appendix

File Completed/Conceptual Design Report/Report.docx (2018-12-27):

RALAZABA ELECTRONICS

PROJECT AMR

Conceptual Design Report

A device trying to extract the plan of their surroundings

Prepared for

Assoc. Prof. Lale ALATAN

Project Start Date: 30.10.2018
Project Completion Date: 18.05.2019

Project Duration: 7 Month

# Executive Summary

RaLaZaBa Electronics design and construct a device that extract and display the plan of the closed area containing placed object the device competes the other pair in terms of the better plan and operation time. We, as RaLaZaBa Electronics, ensure solving the problem in the most efficient and creative way.

The project can be reviewed in two branches. One of them is ‘main constraints and environment specification’ and other one is ‘solution approaches and algorithms’.

Firstly, the environment is created by 50 cm long wall and objects that are limited to

- Cylinders of 10 cm diameter,
- Cylinders of 5 cm diameter,
- Square prisms with 7 cm edge length,
- Prisms with an equilateral triangular base of 8 cm edge length.

In addition, design must be ‘onboard’, there is no communication and no external sensors. There are no constraints about camera or sensor usage in design.

Secondly, our solution to design is consist of some scopes. The scopes:

- Decision and Control Unit
- Environment Sensing Unit
- Motion Unit
- Mapping
- Sensing Unit for Self-Localization
- Motion of sensor
- Power Unit

Decision and Control unit is the brain of the device. Timing of operation and decision are determined by this unit. Eye of the device is Environment Sensing unit which provides the recognition of objects and ambient. Foot of the device is motion unit which help the device go from somewhere to somewhere. Heart of the device is Self-Localization unit which sense the its position to reach the different viewpoints. Power unit is an energy source of the all system to make all duty properly. Mouth of the device is Mapping Output unit which tells results when operation is over. The subsystems should be work properly to extract the mapping of environment at better and faster.

Finally, when we merge all of this subsystem, we create a mapping device.

# Introduction

In this project, the main objective is to design an autonomous robot which plans a bounded environment containing an unknown number of objects by telling the number of objects, their shapes and centers, produces a map and sends it to the monitor. Moreover, the robot should finish this planning operation in the shortest time and minimum error as possible. Main features of the robot are:

- To move in x y directions a bounded environment by visiting all regions of the environment
- To make self-localization for detecting the current position of the robot
- To sense objects and bounds of the environment
- To get all necessary data from the objects and environment and combine these data and transfer to the data processing unit
- To process data and determine the number of objects, their shapes and their center information

These main features are also subsystems of our project. The detailed solution approach and subsystems and overall system definitions are in the following sections.

Currently, we made some experiments for our subsystems and determined some possible solutions for our subsystems. At the first stage of the project, we created a system for sensing the environment and processing measured data to determine objects features and their locations. Then, we moved our robot without actuators and collected data with different locations. With our algorithms, the robot can combine data come from different observation points to building the overall map. Besides, we developed a shape finder algorithm to determine which shapes are in closed area. Measured data gives 2-dimension (x and y) coordinates of the object and closed region. The measured data is not enough to take a better accuracy. So, the data are enriched and classified with respect to shapes.

Our solution idea starts from collecting data from environment via sensing unit. From first collection, the robot finds the closest object relative to its position and builds a road. After completing the road, the robot takes measurements from the object at different points and labels this object as ‘seen’. Then, again it starts to search for new closest and ‘unseen’ object. After the robot labels all objects and identifies their type and location, the robot transmits the map to the monitor via communication channel. Alternatively, probabilistic road-map algorithms like SLAM and PAM can be also used. Since they are relatively complex and hard to implement real time hardware, we chose this idea as alternative.

The first part of this report, we examine the detailed problem statement, measurable objectives. Then we explained our detailed solution approaches, our subsystem definitions, overall system definition, and experimental results. The final part of the report consists of a detailed breakdown of planned work, team’s work sharing as well as Gantt chart to present project timeline. Moreover, test procedures, measure of success, cost analysis and deliverable also explained.

# Problem Statement

The project is required that a robot extracts the features of the closed area and gives the object specification and map of the closed area. In addition, the robot competes with other robots. So, accuracy of plan and operation time is significant.

The problems can be stated as:

- Detection of position and orientation of the surroundings and targets.
- Detection of the position of the vehicle.
- Designing fast, agile and accurate actuator system.
- Optimizing searching algorithm that minimize the time for mapping.

Finally, for the supposed robot can overcome to the problem to reach the goals and missions.

# Solution

## Overall System

In this project, the robot moves autonomously and draws the map of the closed area with the defined 4 types objects. The project is required that the robot senses the environment and decides for the movement and gives the object type, size and orientation as output. Thus, considering this requirement, the project is separated to 7 subsystems and overall system has a closed loop control to make our systems work properly.

The main solution is starting to ON command via button or starting signal to the robot. Then, the actuators of the sensor start to operate, and first data collected. After data collection operation done, it labels the closest object then move to that object. Then data collection operation starts again iteratively. After all objects in the field are labeled and their data is collected, using it observation (the points where the data collected) locations information the final map built with various data processing algorithms. After building the map, the map transmitted to monitor for display.

Our searching algorithm is not the quickest searching algorithm for our project. There are considerable amount probabilistic road-map algorithms like SLAM and PAM. As an alternative these stochastic models can be an alternative solution for road-map algorithms. Since implementing probabilistic models to hardware is excessively difficult, building more deterministic road-map algorithm is more feasible. Therefore, we build our main solution idea based on a deterministic model.


Figure 1 Overall Flow-chart


Figure 2 Block Diagram

There are 7 subsystems which are;

- Decision and Control Unit
- Environment Sensing Unit
- Motion Unit
- Mapping
- Sensing Unit for Self-Localization
- Motion of sensor
- Power Unit

### Interaction and Interfaces of Subsystems


In our system, we need to regulate the voltage level of power unit since most of the microcontrollers and sensors do not tolerate more than 5 volts. This is established via linear or switch mode dc-dc converters. The boundaries in figure 3 represents, voltage levels in the system. Also, we need to isolate the voltage changes due to high-current need of the motion unit. To get rid of the voltage changes, we use a diode and large-value capacitor is used as shown in figure 4.

Figure 3 System interactions and interferences

Figure 4 Filtering Circuit

In environment sensing unit, the sensors communicate with the control unit via 5V tolerable I2C or SPI communication protocols.

In sensing unit for self-localization, it is required to continuous tracking of position change. This task is accomplished by using low-level microcontroller. And the microcontroller communicates with Control unit with I2C with fast clock signal.

In decision unit, we use a main microcontroller with high clock frequency and large memory to conveniently process data coming from environment and self-localization units. In civilian IC market, most of high-performance microcontrollers can tolerate 5 volts.

In motion unit, we need lots of power to actuate the whole mass of the device. Since the unit requires higher voltage and current draw, it is connected to the power unit without any regulation. The communication is established by binary signal. Then, the communication should be isolated via logic level converters. They convert 5V-logic signals to lower or higher voltage levels of logic signals.

## Subsystem Design

### Decision and Control Unit

The unit governs the other subsystems and it makes other subsystems connect each other. Other subsystems send or receive data with the unit. In addition, the control and optimization are made in this manner. Thus, the unit may be divided into two basic parts. One of parts is controlling timing and communication of sensors and movement of actuators. Other one is creating a map and destination point (road map) from taken data.

As seen flow chart Figure 1, data collection from environment sensing and self-localization are not parallel operations. Also, the movement of sensor and robot come true one by one. Therefore, the unit determines the order of operation and commands the operations. Meanwhile, the unit creates map and route. The route is required that movement of devices.

As seen block body diagram Figure 2, the unit connected all other subsystems. The connections are explained as:

- Decision & Control unit with Environment Sensing Unit:

Decision & Control unit give a command that Sensing Unit takes data or not. The taken data are stored and processing for mapping algorithm. The communication between the units come true I^2C protocol. It is explained at Environment Sensing Unit part.

- Decision & Control unit with Actuator for Sensing Unit:

Actuator for Sensing Unit is required for proper data collection in total ambient. It is supplied by motors that rotates the sensing unit. The rotation changes the direction of sensor. Thus, Decision & Control unit commands the motors to rotate specific angles and takes the rotation angle to use in mapping algorithm.

- Decision & Control unit with Actuator for Self-Localization Unit:

After the sensing environment operation, the device can move along specific route that is determined by the decision unit. PID controller are used for motor controlling and reach the destination point properly.

- Decision & Control unit with Self Localization Unit:

Self-localization is used for the creating map from the sensing environment. The sensing environment and self-localization data are merged at decision and control unit. Also, the self-localization data are used to control the robot movement.

Algorithms for Mapping

Decision unit takes data from the sensing units. The data should be converted to map. Before the mapping, the data from environment sensing and self-localization should be merged.

Environment sensing unit gives the distance from sensor direction. The direction of sensor is governed by decision and control unit by actuators. The distance is converted vector space based on device position. The device position is determined by self-localization unit. Thus, the device position and the vector are added. Also, device direction changes after the motion. The direction changes the coordinate system of sensing unit. The changes in coordinate system at different position are illustrated Figure 5. The coordinate system is converted to stationary coordinates by using rotation matrices at Figure 6-7.


Figure 5 Coordinate axes with different direction of the device


Figure 6 Rotation matrix | Figure 7 Rotation of coordinate axes

Therefore, the map is created in this manner. The map is binary matrix that shows whether object is there or not. At every iteration of the different location, the binary matrix is updated.

Finally, the binary matrix is converted to image. It is basically a sketch of environment.

Shape Finder

Shape finder algorithm takes the x-y coordinates information from sensing unit. Then, these x and y information is embedded to a 2D array which is also an image of the environment. Our algorithm must make a decision by using this image. From that time, we have a map as image and we use some image processing tools to be able to identify the properties of the objects in the environment. After preprocessing operation, we have an edged image which contains only the necessary data for decision. Using this edged image, we find all contours on the image firstly, then, we masked these contours according to the area of these contours considering the areas of the objects. To specify the area range, we used experimental results and the area information of the object in our map image in terms of pixels. Then, by identifying the number of sides of the contours that we have, we decide the shape of the objects. After identifying the shapes, we used geometry to find the centers of different types of objects.

Chart 1 Flow chart of shape finder

Road Map Algorithm

As mentioned, mapping algorithm, the robot should move the different location. This location is determined by the probabilistic algorithms. The algorithms are stated as:

SLAM (Plan A):

Simultaneous Localization and Mapping is abstracted SLAM. SLAM is actually a problem that is stated:

- A map is required for localization
- A localization is required for map

Slam problem can be solved by Extended Kalman Filter. Extended Kalman filter is the nonlinear version of Kalman filter. It linearizes current mean and covariance.

EKF SLAM builds the Map with cycle:

- State Prediction
- Measurement Prediction
- Observation
- Data Association
- Update
- Integration

Figure 8 Original map and its correlation matrix | Figure 9 Route map after probabilistic algorithm

Plan(B)

For the simplicity, the devices can follow the wall. Firstly, device goes to wall and stops the specific distance from the wall. In addition, the device stops at every cycle that is determined by the calculation of optimum destination. Figure 10, the probable route is illustrated.


Figure 10 Probable route of the device

### Environment Sensing Unit

In this unit, we need to determine the objects that surround the device like figure 11. To determine the positions and types of objects, we need to transfer the field into a binary understanding of the device. To accomplish this task, we need to understand whether there is an object or not. Our first aim is detecting the object. For this purpose, we can use wave since waves can reflect a specific object and, in this project, our equipment can reflect the waves. Now, we know that we can use waves and there are different types of the module which can make this mission. The second approach is recognizing objects. Our eyes can determine the objects easily since we can understand object by looking at their edges and, our eyes can understand the distance of object dimensions. As we can see in figure 12, we can understand the type of objects. Hence, we decide to use a distance sensor as the first solution since distance modules are inexpensive and we can use easily with a microcontroller.


Figure 11 Realization of Sensing Environment | Figure 12 Realization of Sensing Environment

However, there are some problems and one of them is accuracy. To solve this problem, we decide to use more than one module. Therefore, we can use four distance modules like in the figure 13 but that is not enough because beam width is not large enough and we decide to rotate the circular module. Hence, we rotate 90 degrees clockwise or counterclockwise and after completing the tour, we rotate the opposite direction. Therefore, we scan the whole environment of the device two times.

Figure 13 Sensing module

Second approach to this problem is camera. Camera make 3D- 2D transformation. For this transformation, camera takes 3 data which are Height, Width, Object Distance. The three data are converted to 2 dimensions. In addition, the transformation depends on Focal Length of camera, as seen figure 16. Focal length of camera is constant. Thus, the object distance is calculated by basic geometry. In addition, the width of object is determined by using height of object. The formulations are illustrated at Figure 14-15.

Therefore, the sensing environment the distance of the object is required. The distance of objects is calculated by the camera. In addition, the camera directly gives the width of object that make decision unit works easily.

Figure 14 Formula of

Figure 15 Formula of


Figure 16 Basic Working Principle of Pinhole Camera

### Motion of sensor

We need to sense surrounding the device to extract mapping. To achieve this aim, we need a module that can move 360 degrees. Today, LIDAR has used this type of project, but we have a low-cost objective and, we have a limit on the whole project budget. Since LIDAR is so expensive, we do not want to use it. Due to that, we decided to make a module like LIDAR. Hence, we decided to use step motor to rotate the sensing module since we can find various type of step motor which is fit our cost objective. Since we need to have an accurate result for extracting map, we need a step motor that has a small step angle. Because of that, we can give a lot of point from sensing module in one cycle of rotation. Our rotation plan is that first we rotate sensing unit 90 degree in the clockwise or counterclockwise direction. After completing rotation, we rotate the sensing module in opposite direction.

When step motor does not work properly, we can use a servo motor. In the first plan, we do not want to use servo since the rotation angle of the servo is not constantly divided. For example, when we want to rotate 90 degrees, the servo motor cannot rotate exactly 90 degrees and we can have false labeled data (r is true θ is wrong).

| Servo motor | Step motor
Pros | Small unit volume. Inexpensive. No need for an extra motor driver. | High resolution for the angular position. Less positional error.
Cons | Low angular position resolution. High angular position error. | Costly. The magnetic field generated by step motor can affect the compass or other sensors. Motor driver (DRV8825) needed.

### Motion Unit

In our project, we need to extract a map of unknown environment since in environment, number of objects and shape walls are changeable. Due to that, we need to move the device to collect information to extract the map clearly.

To move properly in mapping field, the device should rotate left or right. To achieve this aim, we think two ideas which are omni wheel and differential drive with the freewheel.

A differential wheeled robot is a mobile robot whose movement is based on two separately driven wheels placed on either side of the robot body. It can thus change its direction by varying the relative rate of rotation of its wheels and hence does not require an additional steering motion.

Table 1 Rotation direction of motor with different voltage level

Left Motor | Right Motor | Direction of Device
0 | 0 | Stop
0 | 1 | Left - Forward
1 | 0 | Right - Forward
1 | 1 | Forward
-1 | -1 | Back
-1 | 0 | Right - Back
0 | -1 | Left - Back

As we can see in the table xx, by using differential drive method, the device can move all direction by giving proper voltage level. Also, as we can see in the picture xx, we need one free turning wheel. However, we do not use any other wheel since as wheel, we use trackball mouse that uses for sensing unit.


Figure 17 Differential motor drive

However, we have a problem and that problem is motor`s response. When we apply some voltage, motor moves but not accurate since when giving high voltage level to motor, motor move suddenly and the device shakes. Therefore, in order to avoid this shaking, we decide to use PID controller. A PID controller continuously calculates an error value e(t) as the difference between a desired setpoint (SP) and a measured process variable (PV) and applies a correction based on proportional, integral, and derivative terms (denoted P, I, and D respectively), hence the name. In practical terms, it automatically applies accurate and responsive correction to a control function. Thanks to PID controller, the device does not shake.

When we face a problem with differential drive technique, we use omni wheel method or mecanum wheel. A robot that uses omni-wheels can move in any direction, at any angle, without rotating beforehand. The omni-wheel is not actually just a single wheel, but many wheels in one. There is the big core wheel, and along the peripheral there are many additional small wheels that have the axis perpendicular to the axis of the core wheel. The core wheel can rotate around its axis like any normal wheel, but now that there are additional wheels perpendicular to it, the core wheel can also move parallel to its own axis. We can see shapes of omni wheel in the figure 18.

Figure 18 Omni Wheel | Figure 19 Vector Diagram

As the first solution, we do not want this driving type since one of the main challenges for using omni wheel is controlling the motion so that the robot is able to go to a desired position with a desired orientation compared to differential drive. Also, we need to use at least three motor for this configuration to move any direction. We can think motor direction as vectors like in the figure 19 and we need three vectors to scan all plane.

However, we can eliminate one of the mousses since we move the device on xy plane, in other words, the device moves forward- backward and right-left but we do not change heading direction during the motion. Therefore, we do not need any rotation angle for self-localization unit.

| Omni wheel | Differential drive with freewheel
Pros | All package omni wheel (motors drivers and chassis and encoders) are available. Flexible position control | Easy to implement. 2 DC motor and 1 L298(dual) are sufficient. Inexpensive
Cons | 2+ DC motor and driver needed. Quite expensive | Mechanical design should be done by us

### Mapping Unit

In this project, we need to show map, type of objects and how many objects there are as output. We decide to use computer screen to achieve this aim. We determine two concepts which are sending information real time and after completing whole process.

As the first solution, the device sends information after completing whole process since sending real time information is extra work load for processor. In other words, the device collects only mapping information to extract map clearly. After completing mapping information, it can send information by using two methods. One of these methods is Wi-Fi. It is the cheapest and easiest method since if we use raspberry pi, raspberry has Wi-Fi module. Thanks to that, we do not any external module and to send picture and text file which has information about how many objects there are in the field, their dimensions and coordinate of center. Second approach is that we can use Bluetooth module to send pictures and text file and thank to raspberry pi, it has Bluetooth module. Hence, we can connect a laptop to send information. However, if we do not use raspberry pi, we need Wi-Fi or Bluetooth module.

As the second solution, we can send information real time. In this configuration, the device both takes data around and sends mapping information to a computer. This requires large parallel processing and also, we need to design a GUI to follow the creating map. We do not want to divide processing of microprocessor since module can lose information.

### Sensing Unit for Self-Localization

Our robot should move autonomously since it is a project requirement. The motion of autonomous devices is governed by the algorithms that mostly rely on probabilistic models such as SLAM, PAM. Since these algorithms are strongly dependent on the environment information and self-localization, both motion and environment sensing have critical significance. At this part of the report, we introduce solution ideas for sensing for the motion of the robot, which we call self-localization.

Self-localization means that the device can measure how much move away start point or former point which device is there so that it can know its location relative to the environment at all operation time. It is also called dead reckoning in literature. Solutions of the self-localization problem are argued at the subsystem. There are our five solution methods.

- 2 mousses (Plan A)
- 1 mouse + compass (Plan B)
- 1 mouse + IMU (Plan C)
- Encoder + IMU (Plan D)
- 1 mouse + Omni drive (Plan E)

2 mousses (Plan A)

PC mousses have capabilities of tracking position inherently. However, they can only give information about linear motion on the plane, not angular motion. To overcome this problem, we used 2 mousses side by side to detect angular motion using their relative motion. Mathematical derivations and related know-how can be found at [1]


Figure 20 Key features of a typical mouse | Figure 21 An example configuration of two mousses

The mouse has better resolution (about 63.5 μm) relative to encoder option [2]. Related measurements and test plants can be found figure 20 and 21. Optical mousses cannot work every plane due to their nature of electromagnetic wave. Therefore, we test them both in the design studio and KKM hall. Although it worked floor of the design studio, it didn’t work at KKM hall’s floor. For that reason, we changed our mouse selection from optical to tracked-ball.

1 mouse + compass (Plan B)

Instead of two mousses, we can use a mouse and a compass. Compass gives three output these x, y, and z coordinate with respect to the magnetic field of the earth. The reason that compass is used in such configuration (with a mouse) is compass gives as rotational information that (direction in XY plane) one mouse cannot give. With directional information, it compensates necessity of the second mouse.

This method like two mousses usage since in this method, with respect to x, y and z values, we calculate rotation angle. One can think that the data comes from the mouse is r, and compass data is θ. Changing cylindrical coordinates (r, θ) to cartesian coordinates (x,y) the position of the robot is easily can tracked.

1 mouse + IMU (Plan C)

An inertial measurement unit (IMU) is an electronic device that measures and reports a body's specific force, angular rate, and sometimes the magnetic field surrounding the body, using a combination of accelerometers and gyroscopes, sometimes also magnetometers. We can use this sensor to perceive rotation device since there will be acceleration when the device rotates. We can use to determine the rotation angle. After finding the rotation angle, like the above case, we determine the device position.

1 mouse + Omni wheel drive (Plan D)

With Omni wheel drive, we can control the robot at 2 dimensions without changing robot heading direction. This extra feature gives us the ability that self-localization with one mouse.

Encoder + IMU (Plan E)

Encoders can be used as position tracker of movement actuators, in this case, DC motors. There are different types of encoders that used for DC motors rotary encoders, optical encoders, and magnetic encoders. We will use incremental encoders since our scope is dead reckoning.

The advantage of encoders is they can easily connect the second shaft of the DC motor. Moreover, their relative size is smaller (considering the mouse option). These make encoder option is the most compact and minimum volume solution. The drawback of the encoders is about reliability. With poorly control or sliminess of the ground, the motor can slip meaning that motor is not actually moved. However, since motors are still rotating the encoder data is not steady meaning that motor is moved. This conflict results in a wrong map because the robot lost its location on the map. Therefore, the position is data is less reliable considering mouse option. To overcome this problem either we can drive the actuators slow acceleration (soft drive) with effective controllers or use a second measurement to confirm position data, or filtering position data with Kalman filters.

- Soft drive

With only one measurement device (only encoder) the actuators controlled smoothly and the controller should have high disturbance rejection. However, the smooth drive can be slow which will affect the total time for mapping operation.

- Kalman filter

After considering two options we decide to use two measurement devices, encoder, and IMU considering operation time and self-position accuracy. Drawbacks are the cost of the subunit and its complexity is increased.

Different drive techniques require different encoder configurations and data processes. In the case of the differential drive, 2 DC motors and 2 encoders are needed. With two channel encoder data, we can catch both rotational and linear motion information. However, both encoder configuration and the data processing unit is completely different with omni wheel drive which will be discussed next sections.

| 2 mousses | 1 mouse + compass | 1 mouse + IMU | Encoder + IMU | 1 mouse + Omni wheel
Pros | High resolution | Mid-high resolution | Mid-high resolution | The overall volume of the subsystem is lower relative to mouse options. It can work almost every flat ground. | High resolution No need for extra data processing*
Cons | Using two mousses can increase overall dimensions Optical mouse cannot work every flow. | Changing magnetic field can affect compass operation. | Optical mouse cannot work every flow. | Aggressive motor movements can create slip, therefore encoder gives false position data. Extra engineering time is required for Kalman filtering Expensive | Requires Omni Drive Expensive

Table 2 Pros and Cons of 5 option

### Power Unit

This is most important unit since if energy does not exist, the device does not move or process anything. In our project, motors draw more current with respect to other component and we use at least three motors which are two 12V DC motor to move device and a step motor to rotate sensing unit. If all of the motor work at the same time, they draw almost 4A current but we do not work together since when the device moves. step do not rotate. Also, we have other components in the device and they can draw almost 1A current. To not have a problem, we need a battery that provides at least 12V - 4A continuously.

## Conceptual Design Tests & Results

To test our conceptual design ideas, we created two test setups. In the first setup, we created a virtual map to determine whether our algorithm works properly to find the shape and position of objects. The maps that we tested are shown in from Figure 22 to Figure 23. In the first map, we inserted a circle sitting at (241,181), square (665,172) and rectangular at (625, 509) coordinates of pixels.


Figure 22 First Test Map | Figure 23 Second Test Map


We created a simulation environment such that, we loaded these maps to a MATLAB script and we selected 3 points for sensing these shapes. From these 3 points, we created lines with different slopes and the intersection points represented the lidar scans with 4.5 degree apart. These lines will represent how the map will be seen by the lidar sensor. Our simulation environment is seen like in Figure 24. In the figure 24, the lines (lidar measurements) is intercepted with the boundaries of the objects. The interceptions are shown in the figure as red dots. The intersection points for the test maps are shown in from Figure 25-26.

Figure 24 The simulation environment, dimensions in mm.

After intersecting lines and our objects, some parts of objects are not shown which will be the case in real data. The missing parts of the objects can be seen in resultant maps. To come up with this problem first, we combined x and y coordinates of resultant map data and converted these data to an image to be able to process and create objects.


Figure 25 Lidar Scan Result for First Map | Figure 26 Lidar Scan Result for Second Map

Thus, after determining the simulated data of mapping, we fed it up to our algorithm to determine the boundaries and edges of the objects using Multiple Kernels. After that, we found contours in the image and using some constraints such as the area of contours and the length of contour arrays, the algorithm gives us the shape and center of the objects with no error as shown in figure 27 to figure 28.

Figure 27 Resultant shapes and centers for First Map | Figure 28 Resultant shapes and centers for Second Map

After confirming our conceptual algorithm is working flawlessly, we took some measurements via VL53L0X on a test setup as shown in Figure 29. In this setup, a servo used to rotate the distance sensor from -60 degree to 60 degree normal to the front surface of the servo. An Arduino Nano is used to transfer the measurements to MATLAB environment. After storage and manipulation of measurements, the data is fed to the algorithm. To have a better understanding, let us make clear definition of the sensor.

STMicroelectronics has various distance measurement sensor that uses time-of-flight. The device measures the distance by using infrared laser pulse. The sensor emits infrared laser pulse and counts the time of flight of infrared light beam to return its avalanche photodiode. The sensor has its circuitry that takes the measurement into meaningful figures. The sensor can communicate with microcontroller via I2C protocol. The sensor is 5V tolerable, enabling us to drive it by microcontroller without any logic level conversion. The device emits beam within the expansion cone of 35 degree. This leads us to use the sensor in close ranges, while the sensor can measure distances up to 2 meters. The sensor takes its measurements and sends distance information within 66 milliseconds. It takes measurements with 1 mm resolution, then resolution of each pixel of map array has 1mm edge length.

Figure 29 The test setup using VL53L0X and servo.

In measurement setup we observe a major error due to beam width of the sensors. As can be seen in figure 30, the measurements taken for cylinder and triangular prism are very similar.


Figure 30 Measurement results of triangular prism


Figure 31 Measurement results of cylindrical prism

Figure 32 Restricting beam width

This problem can be solved by restricting beam width of the infrared light in horizontal axis. We used a vertical slit front of the transmitter to squeeze the light in horizontal axis as shown in figure 32. With this improvement, we obtained sharp measurements as shown in figure 30

We set the measurement environment to test our mapping algorithm with real data. The setup, Figure 33-35, has 3 different viewpoints with respect to object. The test objects are scanned via the lidar sensor from three different points. These measurements are merged by using an algorithm that takes a position of sensor (in 2 Dimension) and angle between stationary coordinate system and sensor data. Normally, the lidar will measure the distance with related angle. This angle information is in the frame of the lidar. We need to project the measurements to the global frame of the map. To accomplish this task, the measurements are rotated using rotational transformation matrix and positioned according to the position vector of the lidar. The output of algorithm is illustrated in Figure 33 to 35.

Later, the obtained data is fed to the object finder algorithm.


Figure 33 First Test Map and its output


Figure 34 Second Test Map and its output


Figure 35 Third Test Map and its output

When we tested our shape finder algorithm with real erroneous data, we had some problem. Most important problem is that the spaces between measured points are large and this causes that our algorithm can find wrong contours. To eliminate this, we added new points to resultant array by adding neighbor points of real data clouds. After that, our thresholding operation worked, and we were able to find true contours. The output for rectangular object is shown in Figure 36. We found the center of rectangle as 146,135. The real center was 146,140. This means that we had 3% error for y coordinate of center. The output for cylindrical object is shown in Figure 37. For cylindrical object we found the center as 154,135. Real center was 146,140. Thus, we had 6% error for x coordinate and 3% for y coordinate. The output for triangular object is shown in Figure 38. Here, we found the center as 148,146. Real center was 184,130. We had 24% error for x coordinate and 12% error for y coordinate.


Figure 36 Output of rectangular object | Figure 37 Output for cylindrical object

Figure 38 Output of triangular object

# Plans

## Cost analysis

Table 3 Cost Table

2 DC Motor | 20$
1 Stepper Motor | 10$
2 Mousses | 2$
4 Distance Module | 10$
Battery | 10$
2 Microcontroller | 5$
1 Microprocessor | 30$
chassis | 30$

We write cost of some important components. We can use other small components. Cost of this project will be almost 150$.

## Foreseeable difficulties

### Error Sources and Possible Solutions

In our design, we might face with some errors due to imperfectness of real-world realization of our ideas. The possible error sources are accumulated in the subsystems that take measurements of the environment and perform sensitive physical motion. In this sense, the error can mainly occur in unit for self-localization, environment sensing unit.

- Environment Unit Errors

Ideally step motor actuate with fixed step size. However, in real life due to nonlinearities step size can change. Especially at turning points (changing rotation direction) the error is maximum due to inertia of the unit. To prevent this effect, we build mechanical obstacle with every 90 degree so that even though step motor saturates (want to turn >90 degree) it regulates itself mechanically.

Another error source is measurement sensor reading errors. Our solution method is modelling the noise gaussian, Laplacian or uniform noise and normalize the measurement with these models.

- Self-localization Errors

Depending on the solutions we used for self-localization we will face different types of errors. Since self-localization is a critical part for accuracy of the map, error handling is mandatory. The robot is always tracking its location information via motion sensing method. We will use secondary information from environment sensor to handling errors. The labelled objects locations are used for feedback.


Figure 39 Error line of distance module


Figure 40 Gannt Chart | Figure 41 Workload of team members

## Deliverables

Documents

Manual: Our company give a user manual for users. Manual contains information about hardware, software components and describes usage of the device.

Technical Support

Our company gives 24/7 technical support by Selman Dinç. The support is accepted via e-mail communication.

Equipment

Device: Robot is provided for users

Platform: 6 walls and 4 objects will be provided for users

Battery and Charging Unit: We will provide chargeable battery to run the robot.

Software

Interface: We will provide a software package which contains a user interface to see a readable map from a screen.

# Conclusion

Our solution idea starts with data collection from the environment. From the first collection, the robot finds the nearest object according to its location and constructs a path. After completion of the path, the robot takes measurements at different points from the object and labels it as 'seen'. Then it starts searching for the newest 'unseen' object. Once the robot has tagged all objects and identified their types and locations, the robot transmits the map to the monitor over a communication channel. Alternatively, probabilistic route map algorithms such as SLAM and PAM can be used. We chose this idea as an alternative because they were relatively complex and real-time hard to implement.

In the first part of this report, we examine detailed problem reporting, measurable objectives. Then we explained our detailed solution approaches, sub-system definitions, general system definition and experimental results. The last part of the report consists of a detailed breakdown of the planned work, the work sharing of the team as well as the Gantt chart to present the project timeline. Test procedures, measurement of success, cost analysis and feasibility are also explained.

# Disclaimer

We, as RaLaZaBa Electronics, guarantee that we will provide you to best product according to standards.

Hardware Engineer | Software Engineer | Software Engineer | System Engineer | Project Manager
Ali AYDIN | Anıl AYDIN | Enes AYAZ | Nail TOSUN | Selman DİNÇ

# References

[1] Dead-Reckoning for Mobile Robots Using Multiple Optical Mouse Sensors

[2] https://alumni.media.mit.edu/~mellis/mouse/ADNS2620.pdf

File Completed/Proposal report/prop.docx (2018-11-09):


# RaLaZaBa Electronics

# Device trying to extract the plan of their surroundings

PROJECT AMR01

Prepared for

Assoc. Prof. Lale ALATAN

Ali AYDIN | 2093326 | +90 538 823 0103 | ali.aydin@metu.edu.tr
Anıl AYDIN | 2030179 | +90 531 861 1820 | anil.aydin@metu.edu.tr
Enes AYAZ | 2093318 | +90 538 978 8499 | enes.ayaz@metu.edu.tr
Nail TOSUN | 2094563 | +90 532 687 1699 | nail.tosun@metu.edu.tr
Selman DİNÇ | 2093722 | +90 537 678 3584 | selman.dinc@metu.edu.tr

Project Start Date: 30.10.2018
Project Completion Date: 18.05.2019

Project Duration: 7 Months

Table of Contents

EXECUTIVE SUMMARY…………………………………...…………………1

INTRODUCTION……………………………………………………………….2

TEAM ORGANIZATION………………………………………………………3

REQUIREMENT ANALYSIS………………………………………………….4

STANDARDS…………………………………………………………………...6

SOLUTION PROCEDURE……………………………………………………..6

DELIVERABLES……………………………………………………………….8

- Documents………………………………………………………………...8
- Technical Support…………………………………………………………8
- Equipment………………………………………………………………...8

CONCLUSION………………………………………………………………….9

APPENDIX A: GANTT CHART………..…...………………………………..10

EXECUTIVE SUMMARY

Robots could one day navigate through constantly changing surroundings with virtually no input from humans, thanks to a system that allows them to build and continuously update a two or three-dimensional map of their environment using low-costs sensors. As the science progress, some researchers want to observe harsh environments like caves with toxic gases, deep underwater surfaces and space environments.

Our company, RaLaZaBa Electronics, is developing robots that extract maps to help to scientists and engineers to explore unknown environments with a reasonable price (under $200) and great robustness.

Our company can provide a great and cheap solution to the problem stated by Electrical- Electronics Engineering department of METU. The required mapping solution of the environment in Mars can be realized by AMR Project. The environment is supposed to be mapped for the experimental tools, which will be oriented by the shape of the objects in the specified environment. We have created their sub-problems and possible solutions. These sub-problems are stated as the following

- Detection of the position and orientation of the surroundings and targets.
- Detection of the position of the vehicle.
- Designing fast, agile and accurate actuator system.
- Optimizing searching algorithm that minimize the time for mapping.

Our approach to these problems may be summarized as;

- A possible list for solutions of the detection of position and orientation of the surroundings and targets
  - Using LIDAR to sense shape of objects and distances
  - Using Camera to sense shape of objects and distances
  - Using distance sensor with encoding motor to sense shape of objects and distances
- A possible list for solutions of the detection of position of the vehicle
  - Using infrared sensor (used in mouse) to sense 2D movement
  - Using ball caster to sense 2D movement
  - Using encoder motors to sense 2D movement
- A possible list for solutions of the fast, agile and accurate actuator system
  - Minimizing weight of robot
  - Using high power motors
- A possible list for solutions of the optimizing searching algorithm that minimize the searching time
  - Using probabilistic model to create non-repetitive route
  - Real time mapping analysis to comprehend route

RaLaZaBa Electronics has an interdisciplinary team that consists of control systems specialist, hardware and software experts. The team has experiences on robotics contests like autonomous RC cars and IEEE contests. Therefore, the team has adequate know-how about the project. Since we have adequate ability to fulfil the requirements, we will deliver the end product before its journey to Mars. The project progress is shown in Appendix A.

INTRODUCTION

Nowadays, map is one of the greatest inventions since we are not lost if we follow directive of map correctly. To map some places, we can use satellite photo or draw top view. Also, we can use some electronic devices such as drones to achieve our goals. What happens if we want to explore a planet and map its surrounding. We cannot use drones due to lack of atmosphere. We can use satellite or a robot. AMR is going to be produced for these purposes.

As RaLaZaBa Electronics we are interested in doing that kind of autonomous mapping robots which will lead this new sector. Our autonomous robot does not need to fly. It moves on the ground and it can identify objects and specify their exact positions in the interested area by sensing the environment and convert the information collected from area to a 2-D map.

During the project AMR, we are supposed to satisfy the requirements of Electrical- Electronics Engineering department of METU. The project is an answer to mapping requirement of the Mars environment that is used to place experimental equipment. This equipment is placed by the shapes of the objects, meaning that mapping of the environment and object detection are emphasized.

In this project, sensing environment takes an important role. A device or robot is supposed to sense its environment and extracts the plan of its surrounding from this sense. The device rambles on the environment and creates a plan of the area. The mapping plan is the output of the device. On the other hand, device produces only map data and we do not control device. For now, to examine the robot, we will use a place which is surrounded by 12 walls and there will be some objects in the area. The robot will not be higher than objects. Our purposes in this examination is that robot should complete drawing area at the shortest time.

This project can be considered as challenging. However, we, RaLaZaBa Electronics, will confidently solve the problem, since we have enough experience, engineering skills and creative ideas. Our members are highly motivated to make this robot.

TEAM ORGANIZATION

Our company RaLaZaBa Electronics have 5 members. Each engineer has theoretical and practical knowledge in their areas. Also, all of them are suitable for the work distribution of the project. The organization of RaLaZaBa Electronics is shown in Figure 1.


Figure 1: Organization Tree of our company

Ali Aydın

Ali uses Python and MATLAB most often for software projects. He has experienced with C# for designing user interface software. He is currently working on C++ and C for DSP applications of motor drives under Research League. He used Verilog for FPGA coding.

Anıl Aydın

He uses C and Python most often for software projects. He has experienced with C# for designing user interface software. He is currently working on microcontrollers and microprocessors like Arduino and Raspberry PI. He is also experienced with image processing applications during his summer internship. Moreover, he worked on MATLAB Simulink applications which will be helpful for the simulations of our subsystems. He has experienced with Altium for PCB design. Besides, he used Verilog for FPGA coding.

Enes Ayaz

He worked IEEE RAS mostly on robotics and embedded systems. He gives lecture about robotics as mentor in RAS. At his first internship he worked on image process and deep learning. He attended workshops about image process (OpenCV), segmentation and ROS in Openzeka autonomous RC car contest. He used Python in many projects mostly on Tensorflow and Keras. He is working on GaN transistors and its physical and mathematical models on Simulink in Research League, Dr. Ozan Keysan’s research group.

Nail Tosun

Nail, is working now with Dr. Ozan Keysan research group Research League under Powerlab. While he working on thermal design and analysis of electric motors, he works also solar power estimation using ANN with Dr. Murat Göl under METU EE STAR. He attended workshops about image process, segmentation, the control theory and introduction to ROS in Openzeka autonomous RC car contest. He works different software project mainly about Python or MATLAB. He has experiences about web development. He used HTML5, CSS3, JavaScript, PHP in his web development projects.

Selman Dinç

He worked on mainly embedded systems and RF links. He has a good command of C++ and MATLAB. He worked as a system engineer during his internship. He worked with CAD programs and he is currently working on Altium Designer. He also knows Verilog HDL.

REQUIREMENT ANALYSIS

The project is improved to use in harsh environments of Mars. The places is hard to maintain vital activity. So, the robot is alone in work area and there is no driver inside. For all reasons, the robot has no chance to make a mistake. Thus, the project has some requirements that restrict the design, and implementation to ensure robot to work properly. The requirements can be separated 2 branches. One is called ‘Mandatory’ that is forced. Other one is ‘voluntary’ that is free to make or not.

Mandatory features:

- Robustness
- Long operating time
- Autonomous
- Fast operation
- Operational safety
- Easy-to-use

Voluntary:

- High resolution
- Light weight

Mandatory Features:

Robustness: The robot must be robust because it works on duty in the harsh environment. The robot must endure until the duty finishes.

Long operating time: The robot continues its activity for at least 10 hours between two sequential refueling/charging. In addition to that requirement, it is supposed to consume minimum power and has to possess high density energy storage.

Autonomous: Communication between robot and server or user for real time is hard to implement at every condition in the harsh environment. Then, the robot must decide and plan your movement by autonomous.

Fast operation: Due to the harsh environment, the robot may be damaged after it is deployed. This leads the mapping operation should be completed in a shortest time.

Operational safety: The device is designed to equip short circuit protections and proper insulation to prevent fatal injuries.

Easy-to-use: The system should be user friendly. After deployment, the mapping output may be needed to transferred to user by a digital medium.

Voluntary:

High Resolution: The aim is to sketch, plot outline of the environment and determine the target objects. The high resolution provides with more precision.

Light: The robot will send to environment and the transportation progress changes cost and feasibility of the project. Weighty devices may not send to space and the weight of robot is crucial at that point.

STANDARDS

Robots compete each other with respect to minimum time for proper map wins the competition. Some definitions about regions, blocks and robots are described. However, physical properties of walls and blocks are left to standard committee.

Rules:

- There is 12 wall pieces with 50 cm long. The pieces are bringing from each group by half.
- There are 8 objects (4 different object)
1. Cylinder with 10 cm diameter.
2. Cylinder with 5 cm diameter.
3. Square prism with an 7cm edge length.
4. Prisms with an equilateral triangular base of 8 cm edge length.
- Any camera or sensor must be on board the device.
- Robots should have maximum 25 cm diameter and height cannot be higher than blocks.
- No communication is allowed between device and outside world.

Standards:

- All objects and walls must be of the same commonly accepted (*) color.
- The height of the objects will be agreed upon (*)
- Time is main competition but there can be an evaluation rubric that is standardize the score.

SOLUTION PROCEDURE

The robot that extracts plan of surrounding consists of four blocks. The blocks are called Sensing Unit, Control Unit, Measurement Unit and Mapping Unit. Sensing unit brings the signal from surroundings and this is helper for creating route of robots. Control unit make a decision to move at route. Measurement unit data extracts the feature of surroundings and objects. Mapping unit takes measurement and sensing data to create a plan of surroundings.

At this point, there is some solution methods to use in units.

Sensing Unit:

- Camera can be used to find the route that is not filled by objects. Camera and its module can be obtained for 10 dollars.

Milestone:

- Detect the object with respect to color.
- Capture the space of objects.
- IR laser distance sensor can be used find route that is not filled by object. One module can be acquired for 0.5 dollar.

Milestone:

- Measure the distance between static two points.
- Measure the distance between one point to radial of points by radial motion.

Control Unit:

- Dc motor with encoder can be used to move robots. They cost 5 dollar each.

Milestone:

- Measure the speed of dc motor.
- Step motor can be used to move robots. The cost is around 2 dollar each.
- Microcontroller needed to process sensing unit data.

Milestone:

- With dummy data, drive the motors.
- Reading encoder data to find speed.

Measurement Unit:

There are two information to extract plan. One of them is object position and other one is vehicle position.

Object position:

- LIDAR can be used to find objects features. For the budget of 200 dollar, the LIDAR module can be hand crafted for 50 dollars. Normally, they cost 200 dollar each.

Milestone:

- The module has to be built.
- The measurement must be established
- Step or servo motor with distance sensor can be used to find objects. The sensor can be built for 14 dollars.

Milestone:

  - Measure the distance by distance sensor.
  - Measure the distance while move radially.
- Camera can be used to find objects. The camera modules with 480-pixel wide sensor is available for 2 dollars.

Milestone:

- Object detection using the camera.

Robot position:

- Robot position can be found by encoder with dc motor.
- Optic Sensor (used in PC mouse to find movement of 2D plane.)

Milestone:

- Reading position data by using “USB”
- Data is processed on the computer

Mapping Unit:

- The unit have a microprocessor that processes measurement unit data and create 2D map and send it to user.

The solution methods will be tested and chosen with respect to plus and minuses. Proposal of solution can be changed if more advantageous and feasible solutions is found.

DELIVERABLES

Documents

Manual: Our company give a user manual for users. Manual contains information about hardware, software components and describes usage of the device.

Technical Support

Our company gives 24/7 technical support by Selman Dinç. The support is accepted via e-mail communication.

Equipment

Device: Robot is provided for users

Platform: 6 walls and 4 objects will be provided for users

Battery and Charging Unit: We will provide chargeable battery to run the robot.

Software

Interface: We will provide a software package which contains a user interface to see a readable map from a screen.

CONCLUSION

RaLaZaBa Electronics will design an autonomous robot which extract map around its surroundings. This product can be used in many different areas such as rescue operations, cave or subsoil research field, space explorations. Many products taken place in this market. However, their cost/price ratio is adequate. That’s why we want to get into this business. We, as RaLaZaBa Electronics offer fully-autonomous, robust, low-power, low-cost product to customers.

The problems are offered as determining the position of both vehicle and its surrounding, effective usage of moving actuators and designing a search algorithm to optimize itself to find minimum path to extract the map with different surroundings.

To solve the problems, we will first classify the problems with their needed know-how.

When the project is finished, this will bring a new approach to rescue operations, space explorations or research at harsh environments. With the help of the robustness and low-cost our technology will easily diffuse the market. At near future, this autonomous robot can be anywhere in any application.

We, as RaLaZaBa Electronics, guarantee that we will provide you to best product according to standards.

APPENDIX A: GANNT CHART


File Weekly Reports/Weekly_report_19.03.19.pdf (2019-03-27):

05/03/2019

# Ralazaba Electronics

Weekly Report

## Done

The Kalman Filter was tested with real measurement with one sensor data which taken from encoders.

Some critical mechanical structures are 3D printed.

## To Do

The Kalman Filter will be tested with HRMTM and encoders together.

Mechanical Implementation will be finalized.


05/03/2019

### Kalman Filter for Self-Localization Problem

Figure 1: The dataset
In this experiment, we tested the capabilities of the Kalman filter. The measurement data taken from encoders can be seen in Figure 1. We added extra measurement noises to the dataset with unit mean and different covariances. Then, we plot both noised signal, ground measurement and estimated values in same figures. The results can be seen in Figure 2,Figure 3Figure 4Figure 5Figure 6Figure 7. Results are also discussed in RMSE
Figure 2: σ = 0. 002 | Figure 3: σ = 0. 005
Figure 4: σ = 0. 01 | Figure 5: σ = 0. 0075

05/03/2019
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

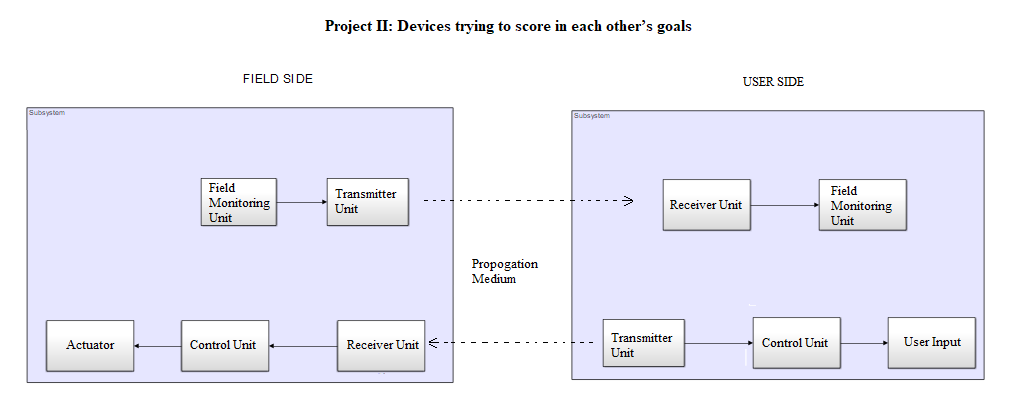
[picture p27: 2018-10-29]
Weekly Reports/PROJECT2 BLOCK.PNG

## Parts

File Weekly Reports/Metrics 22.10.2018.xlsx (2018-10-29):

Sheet: Sayfa1
Project\sMetrics | Image Processing Intensity | Mechanical Design Challenges | Time Cost | Manufacturability | Amount of Subsystem | Know-How | Fun
Project 1 | Image processing is most important sensing unit. | There is no junction, it is easy to design as mechanical. | Not anticipated. | Implementation of sensing unit is hard to sense in high viewpoint | Not anticipated. | It is suitable. | So so.
Project 2 | If Autonomous part is supposed to make, it requires a image processesing | The hockey is beated by mechanical junction. | Not anticipated. | It has complicated mechanical parts. | Not anticipated. | There is no informarion about wave propagation. | It is not funny.
Project 3 | Image processing can be important with respect to using optical sensor. | It is standard vehicle design, it has not specific design. | Not anticipated. | Control system is hard to implement to vehicle | Not anticipated. | Motor driver and control with PID is close to us. | It can be funny, it is competitive.
Project 4 | Image processing is not required. | Moving device is enough. | Not anticipated. | Lidar or sensing sensor design is hard. | Not anticipated. | It is suitable. | It can be funny, there are some trends at industry in similarity with this projects.

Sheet: Sayfa2
 | Image Processing Intensity | Mechanical Design Challenges | Manufacturability | Know-How | Fun | Robust
Weight | 0.13 | 0.11 | 0.18 | 0.20 | 0.21 | 0.17
Project 1 | 1 | 1 | 2 | 3 | 2 | 3
Project 2 | 2 | 2 | 2 | 0 | 0 | 2
Project 3 | 2 | 2 | 3 | 2 | 3 | 2
Project 4 | 3 | 2 | 2 | 3 | 3 | 3
Project 1 Weighted | 0.13 | 0.11 | 0.36 | 0.6 | 0.42 | 0.51 | 2.13
Project 2 Weighted | 0.26 | 0.22 | 0.36 | 0 | 0 | 0.34 | 1.18
Project 3 Weighted | 0.26 | 0.22 | 0.54 | 0.4 | 0.63 | 0.34 | 2.39
Project 4 Weighted | 0.39 | 0.22 | 0.36 | 0.6 | 0.63 | 0.51 | 2.71
 | Image Processing Intensity | Mechanical Design Challenges | Manufacturability | Know-How | Fun | Robust
3 Excellent | Project can be made without image processing. | No calculations and therotical information about mechanical design is not required. | Procurement of materials is effortless, no need special components that are created at 3D printer and CNC. | In past, we worked on the similar project. | All team members can have fun during the project. | No operation failure with respect to environmental changes.
2 Good | Iımage process is assistant to make the project. | Some basic mechanical components such as junction can be used. | Some modules can be hand-crafted. | We are aware of the concepts basis. | Three of team members can have fun during the project. | The project can be optimized for working at different conditions.
1 Unacceptable | The project is based on image processing. | Junction and suspension system is requierd. | Unique materials are required, such as 3D printers and CNC machinary. | Only, we heard the concept. | Two or less of team members have fun during the project. | The project only works at the specified condition.
0 Unsatisfactory | The project totally depends on image processing. | Mechanical arms and joints are required. | A module is needed to re-invented. | Totally stranger. | None of team members can have fun during the project.. | The projects can not work properly with respect to the specified condition.
 | 3 Excellent | 2 Good | 1 Unacceptable | 0 Unsatisfactory
Image Processing Intensity | Project can be made without image processing. | Iımage process is assistant to make the project. | The project is based on image processing. | The project totally depends on image processing.
Mechanical Design Challenges | No calculations and therotical information about mechanical design is not required. | Some basic mechanical components such as junction can be used. | Junction and suspension system is requierd. | Mechanical arms and joints are required.
Manufacturability | Procurement of materials is effortless, no need special components that are created at 3D printer and CNC. | Some modules can be hand-crafted. | Unique materials are required, such as 3D printers and CNC machinary. | A module is needed to re-invented.
Know-How | In past, we worked on the similar project. | We are aware of the concepts basis. | Only, we heard the concept. | Totally stranger.
Fun | All team members can have fun during the project. | Three of team members can have fun during the project. | Two or less of team members can have fun during the project. | None of team members can have fun during the project.
Robust | No operation failure with respect to environmental changes. | The project can be optimized for working at different conditions. | The project only works at the specified condition. | The projects can not work properly with respect to the specified condition.

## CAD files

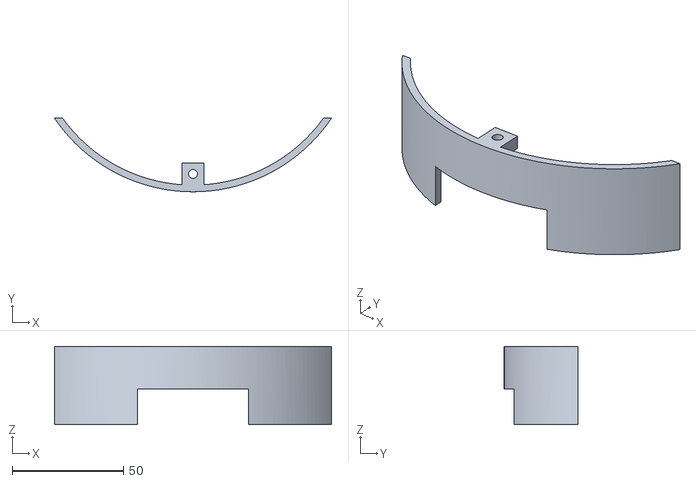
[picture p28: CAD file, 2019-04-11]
CAD/Printed Parts/cover_front.stl
124.3 x 33.0 x 35.0

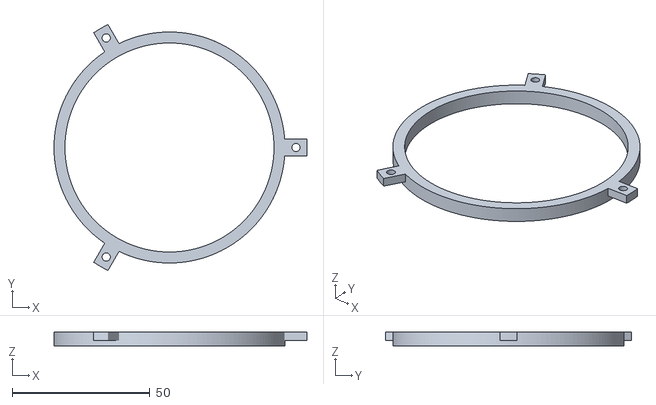
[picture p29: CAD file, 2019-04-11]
CAD/Printed Parts/esu.stl
92.0 x 89.4 x 5.00

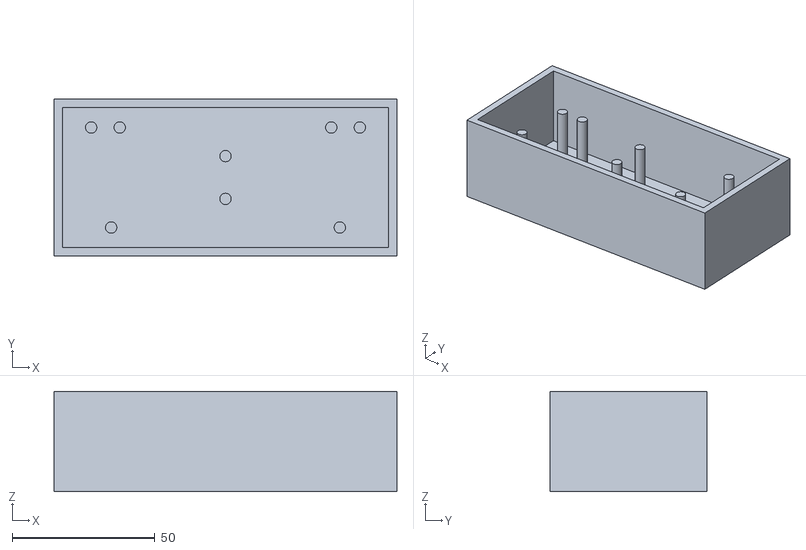
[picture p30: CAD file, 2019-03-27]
CAD/Printed Parts/self_localization_unit.stl
120.0 x 55.0 x 35.0

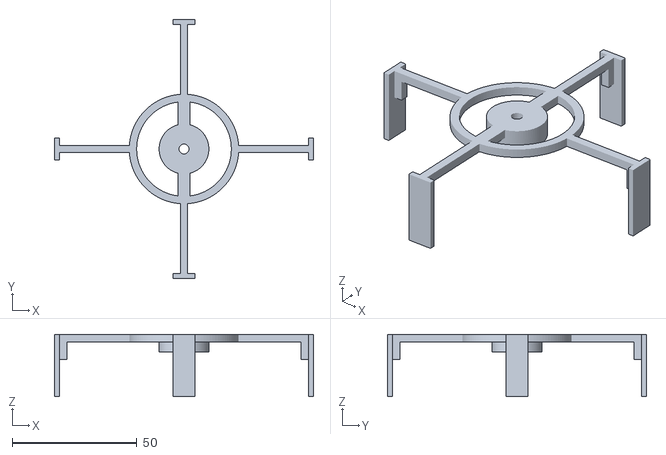
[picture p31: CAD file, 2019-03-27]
CAD/Printed Parts/sensing_unit.stl
104.0 x 104.0 x 25.0

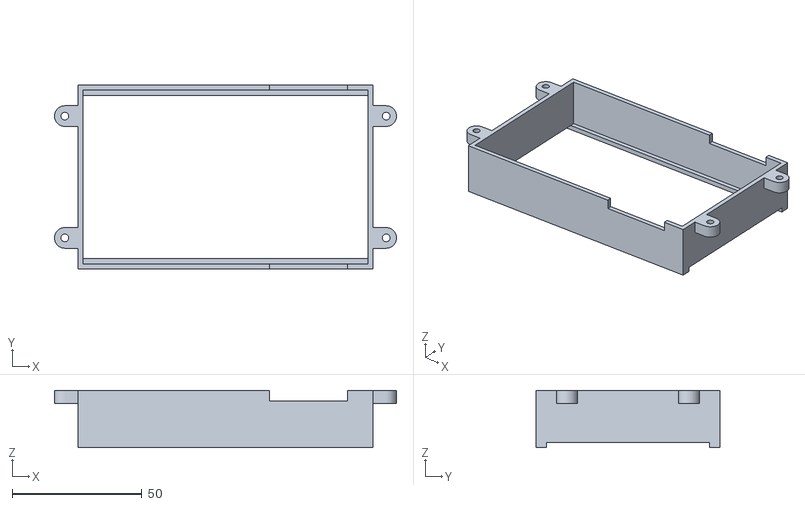
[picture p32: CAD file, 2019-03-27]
CAD/Printed Parts/battery_pack.stl
132.0 x 71.0 x 22.0

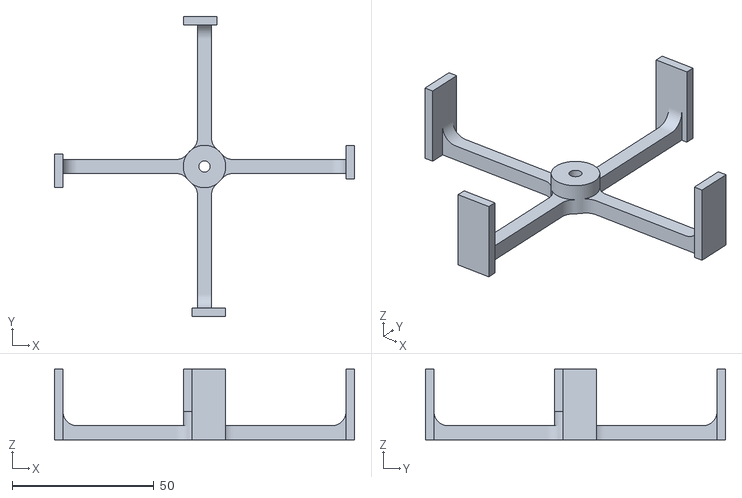
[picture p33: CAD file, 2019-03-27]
CAD/Printed Parts/environment_sensing_unit.stl
106.0 x 106.0 x 25.0

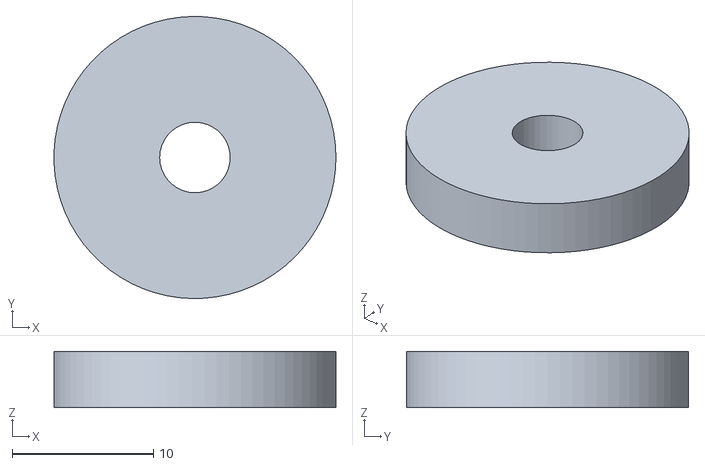
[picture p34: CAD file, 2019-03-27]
CAD/Printed Parts/sensing_unit_back.stl
20.0 x 20.0 x 4.00

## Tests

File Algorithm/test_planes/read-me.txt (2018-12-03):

the test plans are created within the scaling error of 50%. The pixel size is prefencially chosen to be 2.5mm.

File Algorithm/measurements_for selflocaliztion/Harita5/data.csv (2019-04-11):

0.000000000000000000e+00 | 5.400000000000000000e+02 | 5.530000000000000000e+02 | 5.710000000000000000e+02 | 5.830000000000000000e+02 | 6.080000000000000000e+02 | 6.320000000000000000e+02 | 6.620000000000000000e+02 | 6.950000000000000000e+02 | 7.280000000000000000e+02 | 7.550000000000000000e+02 | 7.820000000000000000e+02 | 7.980000000000000000e+02 | 8.340000000000000000e+02 | 8.420000000000000000e+02 | 8.720000000000000000e+02 | 8.830000000000000000e+02 | 9.070000000000000000e+02 | 9.250000000000000000e+02 | 9.390000000000000000e+02 | 9.720000000000000000e+02 | 9.960000000000000000e+02 | 1.012000000000000000e+03 | 1.047000000000000000e+03 | 1.061000000000000000e+03 | 1.072000000000000000e+03 | 1.085000000000000000e+03 | 1.093000000000000000e+03 | 1.105000000000000000e+03 | 1.125000000000000000e+03 | 1.156000000000000000e+03 | 1.165000000000000000e+03 | 1.198000000000000000e+03 | 1.218000000000000000e+03 | 1.246000000000000000e+03 | 1.252000000000000000e+03 | 1.296000000000000000e+03 | 1.325000000000000000e+03 | 1.342000000000000000e+03 | 1.334000000000000000e+03 | 8.242000000000000000e+03 | 8.242000000000000000e+03 | 8.242000000000000000e+03 | 8.242000000000000000e+03 |
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

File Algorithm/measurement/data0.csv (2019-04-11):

0.000000000000000000e+00 | 7.580000000000000000e+02 | 7.740000000000000000e+02 | 8.150000000000000000e+02 | 8.410000000000000000e+02 | 8.550000000000000000e+02 | 8.800000000000000000e+02 | 9.160000000000000000e+02 | 9.250000000000000000e+02 | 9.430000000000000000e+02 | 9.630000000000000000e+02 | 9.790000000000000000e+02 | 9.950000000000000000e+02 | 1.012000000000000000e+03 | 1.022000000000000000e+03 | 1.044000000000000000e+03 | 1.070000000000000000e+03 | 1.094000000000000000e+03 | 1.110000000000000000e+03 | 1.163000000000000000e+03 | 1.149000000000000000e+03 | 1.183000000000000000e+03 | 1.231000000000000000e+03 | 1.275000000000000000e+03 | 1.288000000000000000e+03 | 1.330000000000000000e+03 | 8.242000000000000000e+03 | 8.242000000000000000e+03 | 8.242000000000000000e+03 | 8.242000000000000000e+03 | 8.242000000000000000e+03 | 8.242000000000000000e+03 | 8.242000000000000000e+03 | 8.242000000000000000e+03 | 8.242000000000000000e+03 | 8.242000000000000000e+03 | 8.242000000000000000e+03 | 8.242000000000000000e+03 | 8.242000000000000000e+03 | 8.242000000000000000e+03 | 8.242000000000000000e+03 | 8.242000000000000000e+03 | 8.242000000000000000e+03 | 8.242000000000000000e+03 |
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

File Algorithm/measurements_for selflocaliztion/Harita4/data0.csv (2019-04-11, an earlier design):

0.000000000000000000e+00 | 5.760000000000000000e+02 | 6.050000000000000000e+02 | 6.450000000000000000e+02 | 6.750000000000000000e+02 | 7.090000000000000000e+02 | 7.180000000000000000e+02 | 7.410000000000000000e+02 | 7.640000000000000000e+02 | 7.850000000000000000e+02 | 7.960000000000000000e+02 | 8.200000000000000000e+02 | 8.570000000000000000e+02 | 8.760000000000000000e+02 | 9.030000000000000000e+02 | 9.380000000000000000e+02 | 9.540000000000000000e+02 | 9.710000000000000000e+02 | 1.004000000000000000e+03 | 1.014000000000000000e+03 | 1.039000000000000000e+03 | 1.041000000000000000e+03 | 1.066000000000000000e+03 | 1.085000000000000000e+03 | 1.123000000000000000e+03 | 1.137000000000000000e+03 | 1.153000000000000000e+03 | 1.201000000000000000e+03 | 1.219000000000000000e+03 | 1.247000000000000000e+03 | 1.279000000000000000e+03 | 1.308000000000000000e+03 | 1.331000000000000000e+03 | 8.242000000000000000e+03 | 8.242000000000000000e+03 | 8.242000000000000000e+03 | 8.242000000000000000e+03 | 8.242000000000000000e+03 | 8.242000000000000000e+03 | 8.242000000000000000e+03 | 8.242000000000000000e+03 | 8.242000000000000000e+03 | 8.242000000000000000e+03 | 8.242000000000000000e+03 |
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

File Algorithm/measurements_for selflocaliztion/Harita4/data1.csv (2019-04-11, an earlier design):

0.000000000000000000e+00 | 9.650000000000000000e+02 | 9.790000000000000000e+02 | 9.900000000000000000e+02 | 9.900000000000000000e+02 | 1.009000000000000000e+03 | 1.019000000000000000e+03 | 1.034000000000000000e+03 | 1.052000000000000000e+03 | 1.047000000000000000e+03 | 1.089000000000000000e+03 | 1.094000000000000000e+03 | 1.112000000000000000e+03 | 1.134000000000000000e+03 | 1.148000000000000000e+03 | 1.195000000000000000e+03 | 1.183000000000000000e+03 | 1.187000000000000000e+03 | 1.207000000000000000e+03 | 1.226000000000000000e+03 | 1.248000000000000000e+03 | 1.264000000000000000e+03 | 1.300000000000000000e+03 | 1.294000000000000000e+03 | 1.317000000000000000e+03 | 1.321000000000000000e+03 | 1.329000000000000000e+03 | 1.337000000000000000e+03 | 1.323000000000000000e+03 | 1.331000000000000000e+03 | 1.313000000000000000e+03 | 1.320000000000000000e+03 | 1.309000000000000000e+03 | 1.299000000000000000e+03 | 1.295000000000000000e+03 | 1.292000000000000000e+03 | 1.298000000000000000e+03 | 1.289000000000000000e+03 | 1.283000000000000000e+03 | 1.287000000000000000e+03 | 1.274000000000000000e+03 | 1.247000000000000000e+03 | 1.254000000000000000e+03 | 1.237000000000000000e+03 |
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

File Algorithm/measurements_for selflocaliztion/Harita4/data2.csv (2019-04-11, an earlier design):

0.000000000000000000e+00 | 1.118000000000000000e+03 | 1.122000000000000000e+03 | 1.139000000000000000e+03 | 1.142000000000000000e+03 | 1.157000000000000000e+03 | 1.157000000000000000e+03 | 1.161000000000000000e+03 | 1.161000000000000000e+03 | 1.179000000000000000e+03 | 1.199000000000000000e+03 | 1.187000000000000000e+03 | 1.205000000000000000e+03 | 1.201000000000000000e+03 | 1.210000000000000000e+03 | 1.189000000000000000e+03 | 1.185000000000000000e+03 | 1.164000000000000000e+03 | 1.164000000000000000e+03 | 1.149000000000000000e+03 | 1.132000000000000000e+03 | 1.123000000000000000e+03 | 1.115000000000000000e+03 | 1.102000000000000000e+03 | 1.106000000000000000e+03 | 1.092000000000000000e+03 | 1.091000000000000000e+03 | 1.079000000000000000e+03 | 1.089000000000000000e+03 | 1.073000000000000000e+03 | 1.058000000000000000e+03 | 1.053000000000000000e+03 | 1.028000000000000000e+03 | 1.033000000000000000e+03 | 1.009000000000000000e+03 | 1.012000000000000000e+03 | 1.001000000000000000e+03 | 9.920000000000000000e+02 | 9.890000000000000000e+02 | 9.900000000000000000e+02 | 9.940000000000000000e+02 | 9.770000000000000000e+02 | 9.810000000000000000e+02 | 9.680000000000000000e+02 |
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

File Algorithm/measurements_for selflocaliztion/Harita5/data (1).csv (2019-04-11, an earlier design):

0.000000000000000000e+00 | 7.330000000000000000e+02 | 7.330000000000000000e+02 | 7.280000000000000000e+02 | 7.430000000000000000e+02 | 7.430000000000000000e+02 | 7.520000000000000000e+02 | 7.460000000000000000e+02 | 7.550000000000000000e+02 | 7.570000000000000000e+02 | 7.720000000000000000e+02 | 7.720000000000000000e+02 | 7.860000000000000000e+02 | 7.890000000000000000e+02 | 7.990000000000000000e+02 | 7.950000000000000000e+02 | 8.020000000000000000e+02 | 8.100000000000000000e+02 | 8.000000000000000000e+02 | 8.080000000000000000e+02 | 8.120000000000000000e+02 | 8.130000000000000000e+02 | 8.160000000000000000e+02 | 8.170000000000000000e+02 | 8.240000000000000000e+02 | 8.370000000000000000e+02 | 8.390000000000000000e+02 | 8.400000000000000000e+02 | 8.560000000000000000e+02 | 8.730000000000000000e+02 | 8.780000000000000000e+02 | 8.870000000000000000e+02 | 9.020000000000000000e+02 | 9.120000000000000000e+02 | 9.310000000000000000e+02 | 9.410000000000000000e+02 | 9.470000000000000000e+02 | 9.500000000000000000e+02 | 9.670000000000000000e+02 | 9.650000000000000000e+02 | 9.810000000000000000e+02 | 9.890000000000000000e+02 | 1.002000000000000000e+03 | 1.019000000000000000e+03 |
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

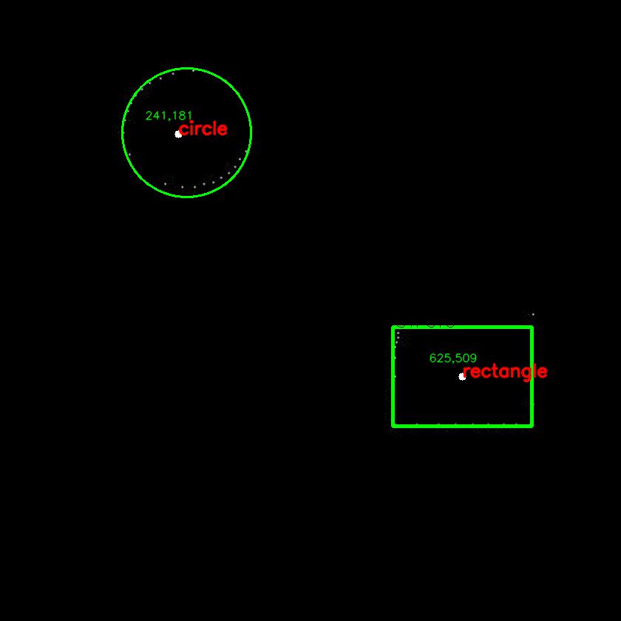
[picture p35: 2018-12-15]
Algorithm/simulation_python_shape_center/resultant_map2.jpg

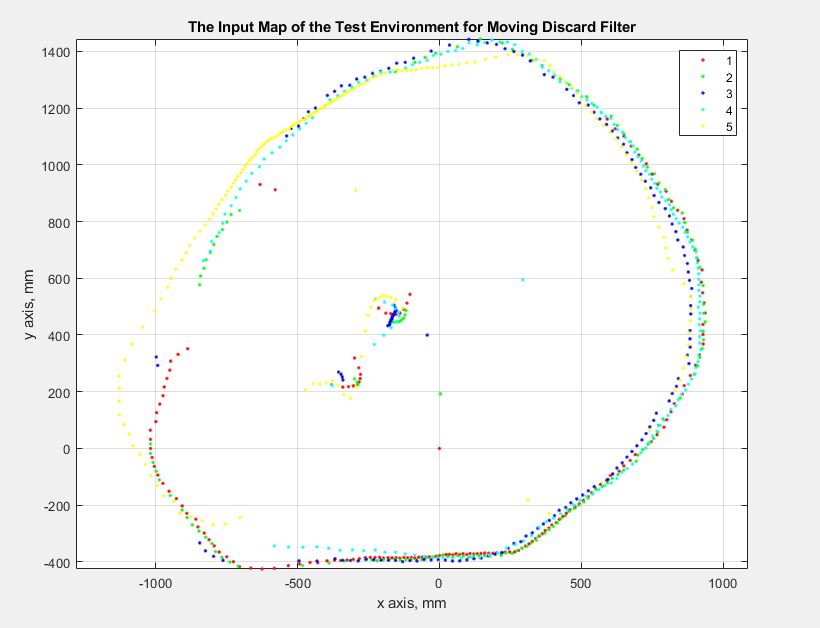
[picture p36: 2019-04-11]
Algorithm/measurements_for selflocaliztion/harita1.JPG

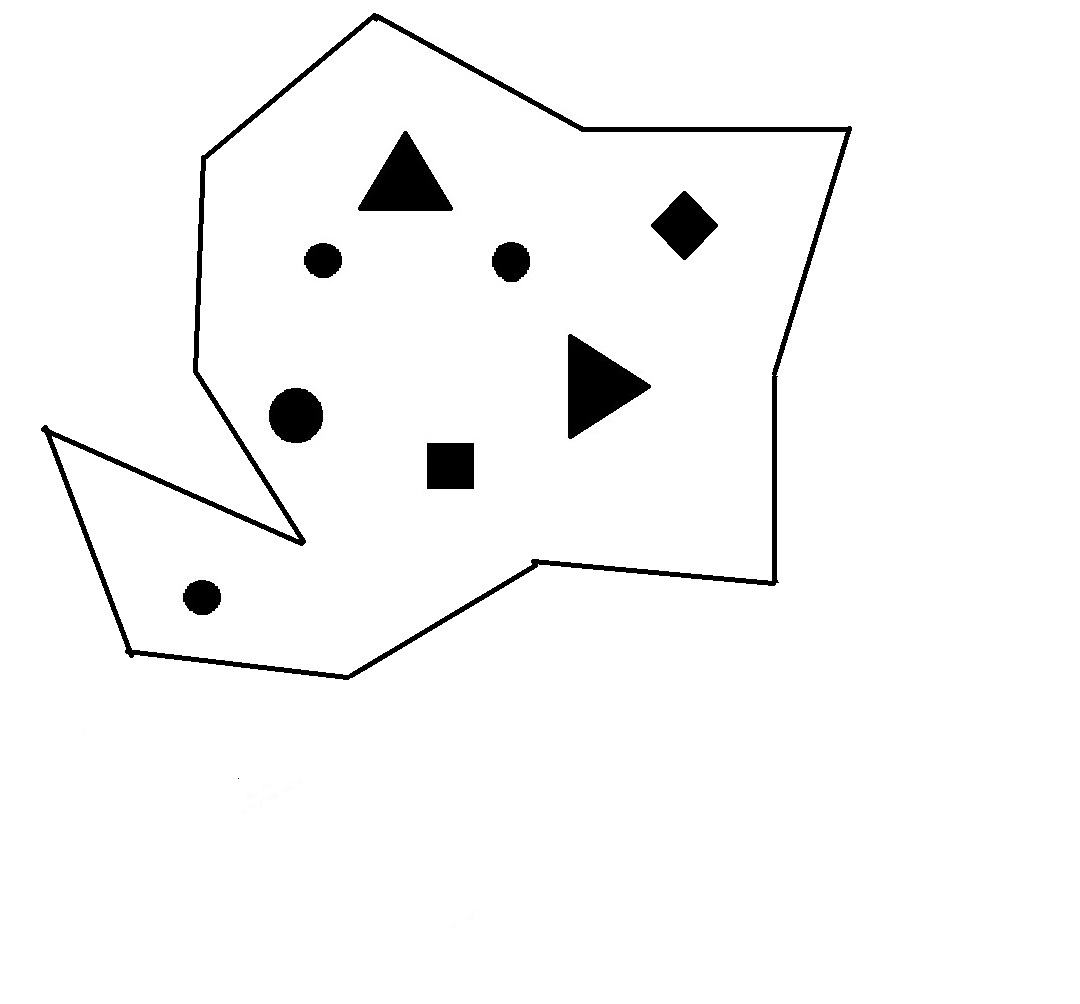
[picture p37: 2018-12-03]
Algorithm/test_planes/test_3.JPG

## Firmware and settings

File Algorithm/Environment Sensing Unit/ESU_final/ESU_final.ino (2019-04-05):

#include <Wire.h>
#include <VL53L0X.h>

//stepper employement
#define DIR 2
#define STP 3
#define SLP 4
#define RST 5
#define M2  6
#define M1  7
#define M0  8
#define EN  9

//sensor employement
#define XSHUT_pin1 10
#define XSHUT_pin2 11
#define XSHUT_pin3 12
#define XSHUT_pin4 13
#define Sensor1_newAddress 41
#define Sensor2_newAddress 42
#define Sensor3_newAddress 43
#define Sensor4_newAddress 44
VL53L0X Sensor1;
VL53L0X Sensor2;
VL53L0X Sensor3;
VL53L0X Sensor4;

int measurement[200];
int i = 0;
void setup()
{ 
  //enabling stepper
  pinMode(DIR,OUTPUT);
  pinMode(STP,OUTPUT);
  pinMode(SLP,OUTPUT);
  pinMode(RST,OUTPUT);
  pinMode(M2,OUTPUT);
  pinMode(M1,OUTPUT);
  pinMode(M0,OUTPUT);
  pinMode(EN,OUTPUT);
  digitalWrite(DIR, LOW);
  digitalWrite(STP, LOW);
  digitalWrite(SLP, HIGH);
  digitalWrite(RST, HIGH);
  digitalWrite(M2, LOW);
  digitalWrite(M1, LOW);
  digitalWrite(M0, LOW);
  digitalWrite(EN, LOW);
  
  //enabling sensors
  Serial.begin(9600); 
  Wire.begin();  
  pinMode(XSHUT_pin1, OUTPUT);
  pinMode(XSHUT_pin2, OUTPUT);
  pinMode(XSHUT_pin3, OUTPUT); 
  pinMode(XSHUT_pin4, OUTPUT); 
  Sensor1.setAddress(Sensor1_newAddress);
  pinMode(XSHUT_pin1, INPUT);
  delay(10);
  Sensor2.setAddress(Sensor2_newAddress);
  pinMode(XSHUT_pin2, INPUT);
  delay(10);
  Sensor3.setAddress(Sensor3_newAddress);
  pinMode(XSHUT_pin3, INPUT);
  delay(10);
  Sensor4.setAddress(Sensor4_newAddress);
  pinMode(XSHUT_pin4, INPUT);
  delay(10);
  Sensor1.setSensor();
  Sensor2.setSensor();
  Sensor3.setSensor();
  Sensor4.setSensor();
}

void loop()
{
  delay(1);
  if(Serial.read() == 'x'){
    
    digitalWrite(DIR, LOW);
    digitalWrite(STP, LOW);
    for(i = 50; i > 0; i--){
      delay(1);
      measurement[i] = Sensor2.readRangeContinuousMillimeters()+52; 
      measurement[i+50] = Sensor1.readRangeContinuousMillimeters()+44;
      measurement[i+100] = Sensor4.readRangeContinuousMillimeters()+52;
      measurement[i+150] = Sensor3.readRangeContinuousMillimeters()+38;
      digitalWrite(STP, LOW);
      digitalWrite(STP, HIGH);
    }
    for(i = 0; i < 200; i++){
      Serial.println(measurement[i]);
    }
    
    digitalWrite(DIR, HIGH);
    digitalWrite(STP, LOW);
    for(i = 0; i < 50; i++){
      delay(1);
      measurement[i] = Sensor2.readRangeContinuousMillimeters()+52; 
      measurement[i+50] = Sensor1.readRangeContinuousMillimeters()+44;
      measurement[i+100] = Sensor4.readRangeContinuousMillimeters()+52;
      measurement[i+150] = Sensor3.readRangeContinuousMillimeters()+38;
      digitalWrite(STP, LOW);
      digitalWrite(STP, HIGH);
    }
    for(i = 0; i < 200; i++){
      Serial.println(measurement[i]);
    }
  }
  
}

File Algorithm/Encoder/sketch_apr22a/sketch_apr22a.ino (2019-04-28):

byte encoderA1 = 2;
byte encoderB1 = 4;
byte encoderA2 = 3;
byte encoderB2 = 5;
byte encoderA1_result = 0;
byte encoderB1_result = 0;
byte encoderA2_result = 0;
byte encoderB2_result = 0;
int rpmcount = 0;
int rpmcount2 = 0;
int i =0;
int mode =0;
void setup() {
  Serial.begin(9600);
  pinMode(encoderA1,INPUT);
  pinMode(encoderB1,INPUT);
  pinMode(encoderA2,INPUT);
  pinMode(encoderB2,INPUT);
  pinMode(10,OUTPUT);
  pinMode(11,OUTPUT);
  digitalWrite(10,LOW);
  digitalWrite(11,LOW);
  attachInterrupt(digitalPinToInterrupt(encoderA1), encoderInterrupt_1, FALLING);
  attachInterrupt(digitalPinToInterrupt(encoderA2), encoderInterrupt_2, RISING);
  
  delay(1000);
}

void loop() {
 if(Serial.available()>0){
  mode = Serial.read()-'0';
 }
 if(mode == 1){
  Serial.println(rpmcount);  
  mode = 0;
 }
 if(mode == 2){
  Serial.println(rpmcount2);
  mode = 0;
 }
 if(mode ==3){
  rpmcount = 0;
  rpmcount2 = 0;
  mode = 0;
 }
}
void encoderInterrupt_1(void){
    encoderA1_result = digitalRead(encoderA1);
    encoderB1_result = digitalRead(encoderB1);
    if(encoderA1_result == HIGH){
        if(encoderB1_result == HIGH) rpmcount = rpmcount + 1;
        else                         rpmcount = rpmcount - 1;
    }
    else{
        if(encoderB1_result == LOW)  rpmcount = rpmcount - 1;
        else                         rpmcount = rpmcount + 1;
    }
//    Serial.print("1: ");
//    Serial.println(rpmcount); 
}
void encoderInterrupt_2(void){
    encoderA2_result = digitalRead(encoderA2);
    encoderB2_result = digitalRead(encoderB2);
    if(encoderA2_result == HIGH){
        if(encoderB2_result == HIGH) rpmcount2 = rpmcount2 + 1;
        else                         rpmcount2 = rpmcount2 - 1;
    }
    else{
        if(encoderB2_result == LOW)  rpmcount2 = rpmcount2 - 1;
        else                         rpmcount2 = rpmcount2 + 1;
    }
//    Serial.print("2: ");
//    Serial.println(rpmcount2);
}

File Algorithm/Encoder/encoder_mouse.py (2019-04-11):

import RPi.GPIO as GPIO
import time
import numpy as np
from motor import *
import csv
import serial
import math

GPIO.setwarnings(False)
#definition for PD controller
Kp = 0.2
Kd = 0.1
Ki = 0.001
#sum_angle_error = 0
desired_angle = 0
desired_x_position = 0
desired_y_position = 0
baseSpeed = 4
maxMotorSpeed = 8
minMotorSpeed = 0
angle_error = 0
last_angle_error = 0
PD_Angle = 0
past_angle_errors = np.zeros(6)
#definition for mouse data
mouse = serial.Serial("/dev/ttyUSB0", 115200)
constant_divider_forMouse = 36.0
dx1 = 0
dy1 = 0
dx2 = 0
dy2 = 0
mouse_sum_x1 = 0
mouse_sum_y1 = 0
mouse_sum_x2 = 0
mouse_sum_y2 = 0
mouse_x_avg = 0
mouse_y_avg = 0
mouse_x_avg_initial = 0
mouse_y_avg_initial = 0
mouse_x_avg_change = 0
mouse_y_avg_change = 0
mouse_length1 = 0
mouse_length2 = 0
mouse_length1_initial = 0
mouse_length2_initial = 0
mouse_length1_change = 0
mouse_length2_change = 0

mouse_angle = 0
mouse_anglesum = 90
mouse_x_position = 0
mouse_y_position = 0
mouse_x_position_initial = 0
mouse_y_position_initial = 10
#definition for encoder data
rpmcount = 0
rpmcount2 = 0
rpmMotor1 = 0
rpmMotor2 = 0
encoder_x_position = 0
encoder_y_position = 0
encoder_x_pos_initial = 25
encoder_y_pos_initial = 0
middlePoint = 0
encoderAngle = 0
encoderAngleSum = 90
rpmMotor1_initial = 0
rpmMotor2_initial = 0
motor1_rpm_change = 0
motor2_rpm_change = 0
#definition for motor 
motor_speed = 0
dutycycle_1 = 0
dutycycle_2 = 0
dutycycle_1_initial = 0
dutycycle_2_initial = 0

counter = 0
counter1 = 0
#input definition
GPIO.setmode(GPIO.BOARD)
GPIO.setup(18, GPIO.IN)  #arduino serial data interrupt pin
GPIO.setup(24, GPIO.IN)  #encoder A (yellow)
GPIO.setup(26, GPIO.IN)  #encoder B (green)
GPIO.setup(29, GPIO.IN)  #encoder A (yellow)
GPIO.setup(31, GPIO.IN)  #encoder B (green)
#in1, in2, PWM, Stanby, (polarity of motors)
motor1 = Motor(40,36,32,38,True)
motor2 = Motor(35,37,33,38,False)
def PI_controller(PI_desired_angle, PI_Angle):
    global counter
    global last_angle_error, angle_error
    global dutycycle_1_initial, dutycycle_2_initial
    past_angle_errors[5] =angle_error
    angle_error = PI_desired_angle - PI_Angle
    motor_speed = Kp * angle_error + Ki * np.sum(past_angle_errors)#Kd * (angle_error - last_angle_error)
    last_angle_error = angle_error
    dutycycle_1 = baseSpeed - motor_speed
    dutycycle_2 = baseSpeed + motor_speed    
    if(dutycycle_1 > maxMotorSpeed):
        dutycycle_1 = maxMotorSpeed
    if(dutycycle_2 > maxMotorSpeed):
        dutycycle_2 = maxMotorSpeed
    if(dutycycle_1 < minMotorSpeed):
        dutycycle_1 = minMotorSpeed
    if(dutycycle_2 < minMotorSpeed):
        dutycycle_2 = minMotorSpeed    
    if(dutycycle_1 > dutycycle_1_initial):
        dutycycle_1 = dutycycle_1_initial + 1
    if(dutycycle_1 < dutycycle_1_initial):
        dutycycle_1 = dutycycle_1_initial - 1
    if(dutycycle_2 > dutycycle_2_initial):
        dutycycle_2 = dutycycle_2_initial + 1
    if(dutycycle_2 < dutycycle_2_initial):
        dutycycle_2 = dutycycle_2_initial - 1
    motor1.drive(dutycycle_1)
    motor2.drive(dutycycle_2)
    dutycycle_1_initial = dutycycle_1
    dutycycle_2_initial = dutycycle_2
    past_angle_errors[4] =  past_angle_errors[5]
    past_angle_errors[3] =  past_angle_errors[4]
    past_angle_errors[2] =  past_angle_errors[3]
    past_angle_errors[1] =  past_angle_errors[2]
    past_angle_errors[0] =  past_angle_errors[1]

def encoderDataMotor_1(A):
    global rpmcount
    encoderA = GPIO.input(24)
    encoderB = GPIO.input(26)
    if(encoderA == 1):
        if(encoderB == 1):
            rpmcount = rpmcount + 1
        else:
            rpmcount = rpmcount - 1
    else:
        if(encoderB == 0):
            rpmcount = rpmcount - 1
        else:
            rpmcount = rpmcount + 1
    return
            
def encoderDataMotor_2(A):
    global rpmcount2
    encoderA = GPIO.input(29)
    encoderB = GPIO.input(31)
    if(encoderA == 1):
        if(encoderB == 1):
            rpmcount2 = rpmcount2 + 1
        else:
            rpmcount2 = rpmcount2 - 1
    else:
        if(encoderB == 0):
            rpmcount2 = rpmcount2 - 1
        else:
            rpmcount2 = rpmcount2 + 1
    return

def mouseInterrupt(A):
    global mouse_sum_x1,mouse_sum_x2,mouse_sum_y1,mouse_sum_y2
    dx1 = int(mouse.readline()) * constant_divider_forMouse / 255
    dy1 = -int(mouse.readline()) * constant_divider_forMouse / 255
    dx2 = int(mouse.readline()) * constant_divider_forMouse / 255
    dy2 = -int(mouse.readline()) * constant_divider_forMouse / 255
    dangle1 = 0.02
    dangle2 = 0.02
    dx1 = dx1 * math.cos(dangle1) - dy1 * math.sin(dangle1)
    dy1 = dx1 * math.sin(dangle1) + dy1 * math.cos(dangle1)
    dx2 = dx2 * math.cos(dangle2) + dy2 * math.sin(dangle2)
    dy2 = dx2 * math.sin(dangle2) + dy2 * math.cos(dangle2)
    mouse_sum_x1 += dx1
    mouse_sum_y1 += dy1
    mouse_sum_x2 += dx2
    mouse_sum_y2 += dy2
    return
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

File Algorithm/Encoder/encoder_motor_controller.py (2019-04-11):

import RPi.GPIO as GPIO
import time
import numpy as np
from motor import *
import csv
import math
GPIO.setmode(GPIO.BOARD)
GPIO.setwarnings(False)
Kp = 1
Kd = 0.8
Ki = 0.01

desired_x_position = 0
desired_y_position = 0
baseSpeed = 5
maxMotorSpeed = 10
minMotorSpeed = 0
desired_angle = 0
interCounter = 0
interCounter2 = 0
loopcounter = 0
#variable definition
headingArray = []
x_pos_array = []
y_pos_array = []
rpmcount = 0
rpmcount2 = 0
rpmMotor1 = 0
rpmMotor2 = 0
x_position = 0
y_position = 0
x_pos_initial = 0
y_pos_initial = 0
angle = 0
past_angle_errors = np.zeros(6)
anglesum = 90
angle_error = 0
last_angle_error = 0
rpmMotor1_initial = 0
rpmMotor2_initial = 0
motor1_rpm_change = 0
motor2_rpm_change = 0
motor_speed = 0
dutycycle_1 = 0
dutycycle_2 = 0
dutycycle_1_initial=0
dutycycle_2_initial  =0
xdata = []
ydata = []
headingdata = []
counter = 0
counter1 = 0
#input definition
GPIO.setup(24, GPIO.IN)  #encoder A (yellow)
GPIO.setup(26, GPIO.IN)  #encoder B (green)
GPIO.setup(29, GPIO.IN)  #encoder A (yellow)
GPIO.setup(31, GPIO.IN)  #encoder B (green)
#in1, in2, PWM, Stanby, (polarity of motors)
motor1 = Motor(40,36,32,38,True)
motor2 = Motor(35,37,33,38,False)
def PI_controller(PI_desired_angle,PI_angle):
    global counter, dutycycle_1_initial, dutycycle_2_initial
    global last_angle_error
    global counter1
    global angle_error
    angle_error = PI_desired_angle - PI_angle
    past_angle_errors[5] =angle_error
    motor_speed = Kp * angle_error + Ki * np.sum(past_angle_errors)##Kd * (angle_error - last_angle_error)#
    last_angle_error = angle_error
    dutycycle_1 = baseSpeed - motor_speed
    dutycycle_2 = baseSpeed + motor_speed
    if(dutycycle_1 > maxMotorSpeed):
        dutycycle_1 = maxMotorSpeed
    if(dutycycle_2 > maxMotorSpeed):
        dutycycle_2 = maxMotorSpeed
    if(dutycycle_1 < minMotorSpeed):
        dutycycle_1 = minMotorSpeed
    if(dutycycle_2 < minMotorSpeed):
        dutycycle_2 = minMotorSpeed    
    if(dutycycle_1 > dutycycle_1_initial):
        dutycycle_1 = dutycycle_1_initial + 1
    if(dutycycle_1 < dutycycle_1_initial):
        dutycycle_1 = dutycycle_1_initial - 1
    if(dutycycle_2 > dutycycle_2_initial):
        dutycycle_2 = dutycycle_2_initial + 1
    if(dutycycle_2 < dutycycle_2_initial):
        dutycycle_2 = dutycycle_2_initial - 1
    motor1.drive(dutycycle_1)
    motor2.drive(dutycycle_2)
    dutycycle_1_initial = dutycycle_1
    dutycycle_2_initial = dutycycle_2
    if((angle_error > -1) & (angle_error < 1)):
        counter += 1
    past_angle_errors[4] =  past_angle_errors[5]
    past_angle_errors[3] =  past_angle_errors[4]
    past_angle_errors[2] =  past_angle_errors[3]
    past_angle_errors[1] =  past_angle_errors[2]
    past_angle_errors[0] =  past_angle_errors[1]

    
def encoderDataMotor_1(A):
    global rpmcount,rpmMotor1, interCounter
    encoderA = GPIO.input(24)
    encoderB = GPIO.input(26)
    if(encoderA == 1):
        if(encoderB == 1):
            rpmcount = rpmcount + 1
        else:
            rpmcount = rpmcount - 1
    else:
        if(encoderB == 0):
            rpmcount = rpmcount - 1
        else:
            rpmcount = rpmcount + 1
    
    interCounter += 1
    return
#            
def encoderDataMotor_2(A):
    global rpmcount2,rpmMotor2, interCounter2
    encoderA2 = GPIO.input(29)
    encoderB2 = GPIO.input(31)
    if(encoderA2 == 1):
        if(encoderB2 == 1):
            rpmcount2 = rpmcount2 + 1
        else:
            rpmcount2 = rpmcount2 - 1
    else:
        if(encoderB2 == 0):
            rpmcount2 = rpmcount2 - 1
        else:
            rpmcount2 = rpmcount2 + 1
    
    interCounter2 += 1
    return
GPIO.add_event_detect(24, GPIO.FALLING, callback = encoderDataMotor_1)
GPIO.add_event_detect(29, GPIO.RISING, callback = encoderDataMotor_2)
try:
    while True:
        if((10 >= abs(x_position - desired_x_position)) & (10 >= abs(y_position - desired_y_position))):  
            motor1.brake() #Short brake
            motor2.brake()
            desired_x_position = int(input("xpos: "))
            desired_y_position = int(input("ypos: "))
        rpmMotor1 = rpmcount / 1.79
        rpmMotor2 = rpmcount2 / 1.65
        #print("rpm1: ",rpmMotor1,"rpm2: ",rpmMotor2)
        motor1_rpm_change = rpmMotor1 - rpmMotor1_initial
        motor2_rpm_change = rpmMotor2 - rpmMotor2_initial
        middlePoint = (motor1_rpm_change + motor2_rpm_change) / 2
        if((motor1_rpm_change >= 0) | (motor2_rpm_change >= 0)):
            angle = (anglesum + (motor1_rpm_change - motor2_rpm_change) / 2.53)%360
        else:
            angle = (anglesum - (motor1_rpm_change - motor2_rpm_change) / 2.53)%360
        
        x_position = middlePoint * math.cos(anglesum * math.pi /180) + x_pos_initial
        y_position = middlePoint * math.sin(anglesum * math.pi /180) + y_pos_initial
        if(angle>240):
            angle -= 360
#        if(counter1 == 0):
        desired_angle = (math.atan2((desired_y_position - y_position) , (desired_x_position - x_position))) * 180 / math.pi            
        PI_controller(desired_angle, angle)
#        else:
#            desired_distance = math.sqrt(math.pow((desired_y_position - encoder_y_position), 2) + math.pow((desired_x_position - encoder_x_position), 2))
            #PD_DistanceController(desired_distance)
#        headingArray.append(angle)
#        x_pos_array.append(x_position)
#        y_pos_array.append(y_position)
        if((angle_error > -1) & (angle_error < 1)):
            counter += 1
#            
#        if(counter >= 1000):
##        if(y_position >= 30):
#            desired_angle = 90
#            last_angle_error = 0
#            baseSpeed = 0
#            maxMotorSpeed = 8
#            minMotorSpeed = -8
#            motor1.brake() #Short brake
#            motor2.brake()
#            time.sleep(1)
#            counter = 0
#            counter1 += 1
#        if(counter1 == 2):
#            motor1.brake() #Short brake
#            motor2.brake()
##            np.asarray(headingArray)
##            np.asarray(x_pos_array)
##            np.asarray(y_pos_array)
##            np.savetxt("headingAngle.csv", headingArray, delimiter = ",")
##            np.savetxt("x_position.csv", x_pos_array, delimiter = ",")
##            np.savetxt("y_position.csv", y_pos_array, delimiter = ",")
#            print("int1: ",interCounter,"int2: ",interCounter2,"loop: ",loopcounter)
#            GPIO.cleanup()
#            break
        anglesum = angle
        x_pos_initial = x_position
        y_pos_initial = y_position
        rpmMotor1_initial = rpmMotor1
        rpmMotor2_initial = rpmMotor2
        loopcounter += 1
        print("x pos:", x_position, "y pos: ", y_position, "heading: ", angle, "counter: ", counter)
#        print("rpm1: ", rpmMotor1, "rpm2: ", rpmMotor2, "heading: ", angle, "counter: ", counter)
except KeyboardInterrupt:
    GPIO.cleanup()

            

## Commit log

2018-10-14 The work done on 14.10.18
    [ratings_14.10.2018.xlsx]
2018-10-18 BS report is written and tentative schedule is add.
    [IC-Project-Timeline-Template-Free-Blank-Timeline-Templates2.xlsx]
2018-10-18 The cover page is created and inserted.
2018-10-19 Completed file has been created. After this, when we finished a phase, we can put files in the completed file in order to avoid chaos.
    [IC-Project-Timeline-Template-Free-Blank-Timeline-Templates2.xlsx]
2018-10-20 sync/ unnecessary files deleted
    [IC-Project-Timeline-Template-Free-Blank-Timeline-Templates2.xlsx]
2018-10-22 first version of metrics are added at exel file
    [Metrics 22.10.2018.xlsx]
2018-10-28 Rubric Draft is added
    [Metrics 22.10.2018.xlsx]
2018-10-28 Metrics of the projects are created, and the projects are weighted.
    [Metrics 22.10.2018.xlsx]
2018-10-29 Metrics are updated, it is more straight forward
    [Metrics 22.10.2018.xlsx]
2018-10-29 update style of metrics
    [Metrics 22.10.2018.xlsx]
2018-10-29 Metices are slightly corrected and coloured.
    [Metrics 22.10.2018.xlsx]
2018-11-25 Budget is updated.
    [Budget.xlsx]
2018-11-25 I uploaded the sensor measurements of various cases. The cylinder and rectandular prisms sit roughly 150mm away. The cylinder is 80mm in diameter and the triangular prism has 60mm of edge lenght.
2018-11-28 I created the item list and their costs in advance
    [Budget.xlsx]
2018-12-01 I organize the budget chart
    [Budget.xlsx]
2018-12-08 I added the code for data generation and transfer code for arduino and matlab.
2018-12-11 I updated the budget list
    [Budget.xlsx]
2018-12-15 the outputs of matlab script whic is about line intersections like lidar scan is added. from these simulation measurement outputs, in python script the map is extracted with shape and center coordina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
2018-12-15 Mouse tracking and its library are created and inserted
2019-03-04 DC motor datasheet is added.
2019-03-04 MappingV2 with intrepolation
    [Map.csv]
2019-03-04 İnterpolation with 4000 data
    [Map.csv]
2019-03-05 Mapping algorithm takes the csv file R,T,SL,H
    [Map.csv, SL_1.csv, SL_2.csv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]
2019-03-06 CAD drawing added
    [0402 Resistor.SLDPRT, 0603 Resistor.SLDPRT, 0805 Capacitor.SLDPRT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]
2019-03-14 encoder reading is completed by using interrupt for two motors simultaneously.
2019-03-16 I made sel localization by using encoder data. Also, by using motor.py and encoder position data, device is driven.
2019-03-16 3D Printed parts are added.
2019-03-20 Kalman filter code is added
    [xdata.csv, xdata_predicted.csv, ydata.csv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]
2019-03-20 CAD drawings of required units are added.
    [0402 Resistor.SLDPRT, 0603 Resistor.SLDPRT, 0805 Capacitor.SLDPRT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]
2019-03-27 Past (CDDR document)
    [Map.csv]
2019-04-04 Everything about Environment Sensing Unit and HRMT Unit is added. All code pieces can be found.
    [a_successive_result_from_two_different_measurements.xlsx]
2019-04-07 RoadMap Algorithm are added
    [Map.csv, SL_1.csv, SL_2.csv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]
2019-04-10 Encoder data is optimized and mouse is arranged by using rotation matrix property.
2019-04-11 Real time measurements and imrovements in some algorthm. Test plans are added.
    [data.csv, data0.csv, data1.csv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]
2019-04-11 Required 3D Cad desgins are added.
    [cover_front.stl, esu.stl]
2019-04-11 HRTM and encoder unit are merged. Also, some optimizations on codes
2019-04-11 Some required measuremtns are added.
    [data (1).csv, data.csv, data0.csv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]
2019-04-16 Road Map algorithm was added
    [data.csv, data1.csv, data10.csv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]
2019-04-24 Recognition algorithm in MATLAB and Python
    [data0.csv, data1.csv, data10.csv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]
2019-04-28 Mapping main.py is added. For encoder reading, arduino interrupt is added.
2019-05-15 Recognition completed.
    [data1.csv, data10.csv, data100.csv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]
